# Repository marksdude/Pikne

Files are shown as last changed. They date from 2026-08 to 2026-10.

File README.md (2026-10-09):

# Pikne
A modular and repairable power bank
  
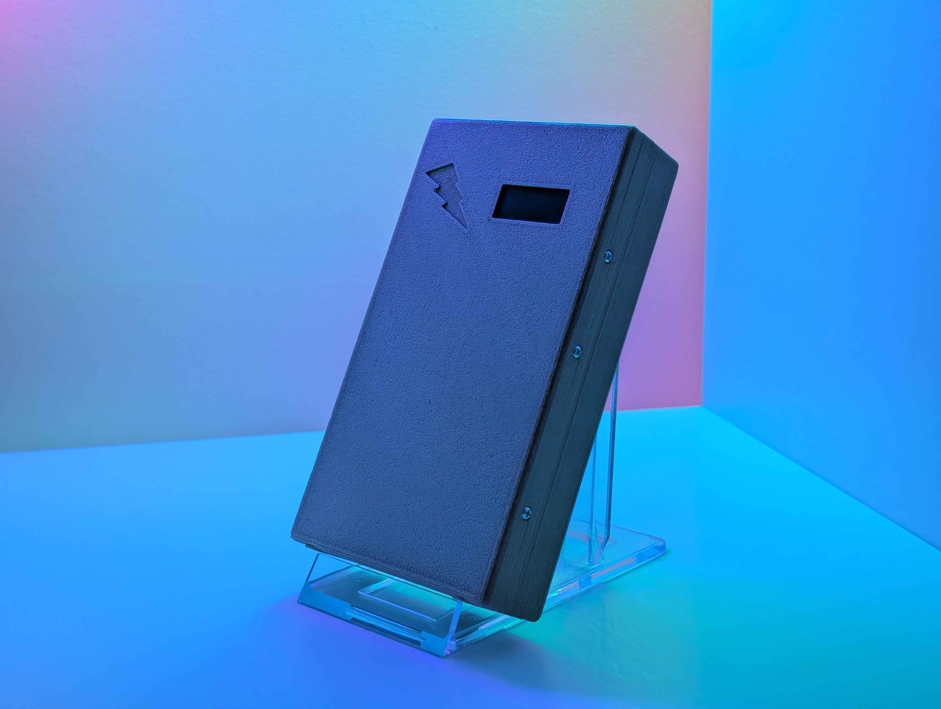
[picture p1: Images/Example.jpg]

Picture of rev 1.0 nonworking build
# Features:
- USB PD output up to 60W
- 0.91 inch OLED for status monitoring
- Attachable modules
- Repairable design
- 80WH capacity
- Based on the BQ25792 and TPS25751
- One USB-C output
# Modules:
- LED controller - Allows you to control LEDs with Home Assistant.  
  - Features:
    - Up to 2.5A output
    - 5V output
    - Home Assistant integration
    - Power monitoring on each output
    - 2 monochrome outputs, 1 RGB output and 1 addressable LED output 
      - **Note:** RGB and the monochrome outputs can't be used simultaneously.
    - ESP32-C3 based
- Flashlight
  - Features:
    - 6600lm max brightness
      - **Note:** The LEDs probably won't be able to run at max brightness for very long.
    - PWM dimmable
    - STM32L011F3 based
# Coming modules
- LiPo charger - Allows you to charge up to 4S LiPos from your power bank
# Why did I make this?
It all started because I was tired of changing the AA batteries in my mom's battery-powered lights. I wanted to make the process faster and less wasteful, so I thought it would be a good idea to design an easily removable, rechargeable battery pack for the lights and also integrate them with Home Assistant. The original idea was going to have 2 parts the battery pack and a controller board. They were supposed to be held together with magnets, connected with pogo pins and communicate over UART. Then I thought, why not turn the battery pack into a power bank so it could be used for things other than the lights? That's what I did. The idea of making the battery pack easily removable led me to make the power bank modular. That's how Pikne was born.

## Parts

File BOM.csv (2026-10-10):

 | Qty Needed | Min Purchase Qty | Unit | Price (total) (USD) | Price (total) (EUR) | Link | Notes
POWER BANK
Main PCB | 1 | 5 | pcs | 7,1 | 6,1 | https://jlcpcb.com/ | OSP Surface Finish, 4 layer, 60x30mm
Main PCB components | 1 | 1 | set | 39,81 | 34,49 |  | More info in the main PCB BOM, located in the main PCB folder
BMS PCB | 1 | 5 | pcs | 7,1 | 6,1 | https://jlcpcb.com/ | OSP Surface Finish, 4 layer, 50.85x18mm
BMS components | 1 | 1 | set | 18,01 | 15,52 |  | More info in the BMS BOM, located in the BMS folder
Battery | 4 | 1 | pcs | 16,01 | 13,8 | https://www.nkon.nl/en/samsung-inr21700-58e-5330mah-10-7a.html | 4 cells for 2S2P pack
isolation paper for the battery | 4 | 80 | pcs | 2,26 | 1,95 | https://www.nkon.nl/en/1x-20700-21700isolatiepapier-groen.html
Nickel strip for the battery | 0,4 | 1 | m | 3,77 | 3,25 | https://www.nkon.nl/en/1-meter-nikkel-batterijsoldeerstrip-10mm-0-10mm.html
Pogo connector PCB | 1 | 5 | pcs | 4,2 | 3,61 | https://jlcpcb.com/ | OSP Surface Finish, 2 layer, 39x10mm, black solder mask, 0.8mm thickness
Pogo connectors | 1 | 5 | pcs | 10,4 | 8,97 | https://www.amazon.de/-/en/Liseng-Magnetic-Connector-Position-Through/dp/B0B1771YT4 | Amazon seemed cheaper than Aliexpress, also used in the modules
ESD diode | 2 | 1 | pcs | 1,86 | 1,6 | https://www.mouser.ee/en/ProductDetail/Texas-Instruments/TPD2E2U06DCKRG4?qs=7%2F6SraaimPTS3zhvanrNFw%3D%3D | For the pogo connector, also used in the modules
JST connector | 2 | 1 | pcs | 1,1 | 0,95 | https://www.mouser.ee/en/ProductDetail/JST-Commercial/S3B-ZR-SM4A-TFLFSN?qs=QpmGXVUTftHs30qFaTPFrg%3D%3D | JST ZR S3B SM4A for the pogo connector, also used in the modules
Button PCB | 1 | 5 | pcs | 4,2 | 3,62 | https://jlcpcb.com/ | OSP Surface Finish, 2 layer, 29.9x8mm, black solder mask, 0.8mm thickness
Button | 1 | 1 | pcs | 1,13 | 0,97 | https://www.mouser.ee/en/ProductDetail/Omron-Electronics/B3U-1000P?qs=AO7BQMcsEu4ip80xyf2FwA%3D%3D
JST connector | 1 | 1 | pcs | 0,53 | 0,46 | https://www.mouser.ee/en/ProductDetail/JST-Commercial/S2B-ZR-SM4A-TFLFSN?qs=QpmGXVUTftFg0hrqdkvc8w%3D%3D | JST ZR S2B SM4A for the button
NTC | 4 | 1 | pcs | 2,69 | 2,33 | https://www.mouser.ee/en/ProductDetail/Semitec/103AT-2?qs=wgO0AD0o1vvcDzsKguD%252Bew%3D%3D | For sensing battery temperature
 |  |  | Total | 120,17 | 103,72
LED CONTROLLER MODULE
PCB | 1 | 5 | pcs | 4,1 | 3,53 | https://jlcpcb.com/ | OSP Surface Finish, 2 layer, 75x18.35mm, black solder mask, 0.8mm thickness
Components | 1 | 1 | set | 21,75 | 18,75 |  | More info in the LED controller BOM, located in /Modules/LED controller/PCB/LED controller
Pogo connector PCB | 1 | 5 | pcs | 4,2 | 3,61 | https://jlcpcb.com/ | OSP Surface Finish, 2 layer, 37.5x10mm, black solder mask, 0.8mm thickness
 |  |  | Total | 30,05 | 25,89
ALL TOGETHER
Power bank |  |  |  | 120,17 | 103,72
LED controller module |  |  |  | 30,05 | 25,89
 |  |  | Total | 150,22 | 129,61

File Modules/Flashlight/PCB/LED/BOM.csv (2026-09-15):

Id | Designator | Footprint | Quantity | Designation | Price (total) (EUR) | Link | Part number
1 | D1, D2, D3, D4, D5, D6, D7, D8, D9, D10, D11, D12, D13, D14, D15, D16, D17, D18, D19, D20, D21, D22, D23, D24, D25, D26, D27, D29, D30, D31 | Q9LR37 | 30 | LED | 23,22 | https://www.mouser.ee/en/ProductDetail/ams-OSRAM/GW-Q9LR37EMM2MF531?qs=dhCoiiGcT1LN8Ex%252B%252BcgNRA%3D%3D | GW Q9LR37EMM2MF531
2 | TH1 | R_0402_1005Metric | 1 | Thermistor_NTC | 0,09 | https://www.mouser.ee/en/ProductDetail/Murata-Electronics/NCU15XH103J6SRC | NCU15XH103J6SRC
 |  |  |  | Total (EUR) | 23,31
 |  |  |  | Total (USD) | 27,07

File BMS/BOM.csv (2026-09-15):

Id | Designator | Footprint | Quantity | Designation | Price (total) (euro) | Link
1 | C1, C3, C5 | C_0402_1005Metric | 3 | 0.1uf | 0,15 | https://www.mouser.ee/en/ProductDetail/Murata-Electronics/GRM155R62A104ME14D?qs=IPQhFcwEUOgMaa1bf1Gh1w%3D%3D
2 | C2, C4, C6, C7 | C_0402_1005Metric | 4 | 1uf | 0,27 | https://www.mouser.ee/en/ProductDetail/TAIYO-YUDEN/MCASE105SB5105KFNA01
3 | C8 | C_0402_1005Metric | 1 | 1nf | 0,09 | https://www.mouser.ee/en/ProductDetail/Murata-Electronics/GRM155R61A102KA01D
4 | D2 | D_SOD-323_HandSoldering | 1 | BAT54HT1G | 0,16 | https://www.mouser.ee/en/ProductDetail/onsemi/BAT54HT1G?qs=vLkC5FC1VN%252BK3ZQA%252ByHPIA%3D%3D
5 | IC1 | QFN40P400X400X80-33N-D | 1 | BQ41Z50RSNR | 4,88 | https://www.mouser.ee/en/ProductDetail/Texas-Instruments/BQ41Z50RSNR?qs=2FehpBK1j95h5MRSV2e3rA%3D%3D
6 | J2, J4 | JST_VH_S4P-VH_1x04_P3.96mm_Horizontal | 2 |  | 0,52 | https://www.mouser.ee/en/ProductDetail/JST-Commercial/S4P-VHLFSN?qs=QpmGXVUTftGoUBD%252BPjD3%2FQ%3D%3D
7 | J3 | JST_ZH_B3B-ZR_1x03_P1.50mm_Vertical | 1 | out | 0,21 | https://www.mouser.ee/en/ProductDetail/JST-Commercial/B3B-ZR-3.4LFSN?qs=cdbOS8ANM9A4HB4OVixO0g%3D%3D
8
9 | J5 | JST_ZH_B6B-ZR_1x06_P1.50mm_Vertical | 1 | in | 0,28 | https://www.mouser.ee/en/ProductDetail/JST-Commercial/B6B-ZR-3.4LFSN?qs=QpmGXVUTftFTUFNLJp%252BAEQ%3D%3D
10 | Q1, Q2 | TDSON-8-1 | 2 | CSD18512Q5B | 4,12 | https://www.mouser.ee/en/ProductDetail/Texas-Instruments/CSD18512Q5B?qs=34RfhUjJmKeWWuFTpy7f3A%3D%3D
11 | R1, R13 | R_0603_1608Metric | 2 | 10k | 0,09 | https://www.mouser.ee/en/ProductDetail/YAGEO/RT0603FRE1310KL?qs=sGAEpiMZZMtlubZbdhIBIE441mth93wmotyGspRJebc%3D
12 | R2, R3, R4, R10, R11 | R_0402_1005Metric | 5 | 100 ohm | 0,08 | https://www.mouser.ee/en/ProductDetail/Bourns/CR0402-FX-1000GLF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
13 | R5 | R_Shunt_Vishay_WSK2512_6332Metric_T2.21mm | 1 | R_Shunt | 2,55 | https://www.mouser.ee/en/ProductDetail/Vishay-Dale/WSK25123L000FEA?qs=l%252BoLuM8chxoqEmTKH2yXCw%3D%3D
14 | R6 | R_0603_1608Metric | 1 | 100 ohm | 0,09 | https://www.mouser.ee/en/ProductDetail/Vishay/CRCW0603100RFKECC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
15 | R7, R12 | R_0402_1005Metric | 2 | 5.1k | 0,08 | https://www.mouser.ee/en/ProductDetail/YAGEO/RC0402FR-075K1L
16 | R8, R9 | R_0402_1005Metric | 2 | 10M | 0,08 | https://www.mouser.ee/en/ProductDetail/YAGEO/AC0402DR-0710ML?qs=w%2Fv1CP2dgqr%252BP88vX9ZHng%3D%3D
17 | SW1, SW2 | SW_SPST_B3U-1000P | 2 |  | 1,87 | https://www.mouser.ee/en/ProductDetail/Omron-Electronics/B3U-1000P?qs=AO7BQMcsEu4ip80xyf2FwA%3D%3D
 |  |  |  | Total (EUR) | 15,52
 |  |  |  | Total (USD) | 18,01

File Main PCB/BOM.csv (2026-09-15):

Id | Designator | Footprint | Quantity | Designation | Price (total) (EUR) | Link | Part number
1 | C1, C13, C14, C16, C21, C23, C25, C33, C41, C46, C48, C40 | C_0402_1005Metric | 12 | 0.1uf | 0,18 | https://www.mouser.ee/en/ProductDetail/Murata-Electronics/GRM155R62A104ME14D?qs=IPQhFcwEUOgMaa1bf1Gh1w%3D%3D | GRM155R62A104ME14D
2 | C2 | C_0402_1005Metric | 1 | 1nf | 0,1 | https://www.mouser.ee/en/ProductDetail/Walsin/0402B102M500CT?qs=ZrPdAQfJ6DMOvVoHhNQARQ%3D%3D | 0402B102M500CT
3 | C3, C4 | C_0402_1005Metric_Pad0.74x0.62mm_HandSolder | 2 | 330pf | 0,16 | https://www.mouser.ee/en/ProductDetail/Samsung-Electro-Mechanics/CL05C331JB5NNNC | CL05C331JB5NNNC
4 | C5, C8, C27, C43 | C_0402_1005Metric | 4 | 10nf | 0,14 | https://www.mouser.ee/en/ProductDetail/Murata-Electronics/GRT155R71E103KE01J | GRT155R71E103KE01J
5 | C6, C20 | C_0402_1005Metric | 2 | 4.7uf | 0,4 | https://www.mouser.ee/en/ProductDetail/KYOCERA-AVX/KGM05CR51C475MH?qs=Jm2GQyTW%2Fbi2to8BOB9y6A%3D%3D | KGM05CR51C475MH
6 | C9 | C_0402_1005Metric_Pad0.74x0.62mm_HandSolder | 1 | 2.2nf | 0,1 | https://www.mouser.ee/en/ProductDetail/Murata-Electronics/GRM155R71H222KA01D?qs=sT7emLDNC7VMoN5Pn9EW7g%3D%3D | GRM155R71H222KA01D
7 | C10, C35 | C_0603_1608Metric_Pad1.08x0.95mm_HandSolder | 2 | 10uf | 0,21 | https://www.mouser.ee/en/ProductDetail/Murata-Electronics/GRM188R61A106ME69D | GRM188R61A106ME69D
8 | C11, C12, C42 | C_0805_2012Metric | 3 | 10uf | 1,21 | https://www.mouser.ee/en/ProductDetail/TDK/C2012X5R1V106K085AC?qs=6JAMGB%252BEdky%252BlYMcTLhFyA%3D%3D | C2012X5R1V106K085AC
9 | C15, C17, C18, C19, C22, C24, C26, C29, C30, C37, C36 | C_0603_1608Metric | 11 | 10uf | 0,97 | https://www.mouser.ee/en/ProductDetail/KYOCERA-AVX/0603YD106KAT2A | 0603YD106KAT2A
10 | C31, C32 | C_0402_1005Metric_Pad0.74x0.62mm_HandSolder | 2 | 0.047uf | 0,14 | https://www.mouser.ee/en/ProductDetail/Murata-Electronics/GRM155R71H473ME14J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 | GRM155R71H473ME14J
11
12 | C38, C39 | C_0805_2012Metric | 2 | 22uf | 1,1 | https://www.mouser.ee/en/ProductDetail/TAIYO-YUDEN/MSAST21GBB5226MTNC12?qs=tlsG%2FOw5FFifOAmFpx5Mxw%3D%3D | MSAST21GBB5226MTNC12
13 | C40
14 | C44 | C_0402_1005Metric | 1 | 1100pf | 0,13 | https://www.mouser.ee/en/ProductDetail/KEMET/C0402C112J4HACAUTO?qs=j%252B1pi9TdxUbzRsbRCfs5CQ%3D%3D | C0402C112J4HACAUTO
15 | C45 | C_0603_1608Metric | 1 | 4.7uf | 0,27 | https://www.mouser.ee/en/ProductDetail/Murata-Electronics/GRM188R6YA475ME15D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 | GRM188R6YA475ME15D
16 | C47 | C_0402_1005Metric_Pad0.74x0.62mm_HandSolder | 1 | 22pf | 0,11 | https://www.mouser.ee/en/ProductDetail/Walsin/0402N220K500CT | 0402N220K500CT
17 | C49 | CP_Radial_D5.0mm_P2.50mm | 1 | 100uf
18 | C50, C51 | C_1210_3225Metric_Pad1.33x2.70mm_HandSolder | 2 | 47uf | 1,15 | https://www.mouser.ee/en/ProductDetail/Samsung-Electro-Mechanics/CL32A476MOJNNNE | CL32A476MOJNNNE
19 | D1 | D_SOD-323_HandSoldering | 1 |  | 0,23 | https://www.mouser.ee/en/ProductDetail/Taiwan-Semiconductor/BAT42WSH-RRG?qs=jcD%2FCkGBYeNbLXauDmsPEg%3D%3D | BAT42WSH RRG
20 | D2 | D_SMC | 1 |  | 0,95 | https://www.mouser.ee/en/ProductDetail/Comchip-Technology/CDBC540-G?qs=tw%252BuQ%2FB6PO2ExpPYY64Vzw%3D%3D | CDBC540-G
21 | D3 | LED_0603_1608Metric | 1 | LED blue | 0,15 | https://www.mouser.ee/en/ProductDetail/Wurth-Elektronik/150060BS75000 | 150060BS75000
22 | J1 | USB_C_Receptacle_GCT_USB4125-xx-x-0190_6P_TopMnt_Horizontal | 1 | USB_C_Receptacle_PowerOnly_6P | 0,53 | https://www.mouser.ee/ProductDetail/GCT/USB4125-GF-A?qs=KUoIvG%2F9IlaIQ4zBJ6gLeA%3D%3D | USB4125-GF-A
23 | J2 | JST_VH_S4P-VH_1x04_P3.96mm_Horizontal | 1 | JST VH S4P | 0,26 | https://www.mouser.ee/en/ProductDetail/JST-Commercial/S4P-VHLFSN?qs=QpmGXVUTftGoUBD%252BPjD3%2FQ%3D%3D | S4P-VH(LF)(SN)
24 | J3, J4 | JST_ZH_B3B-ZR_1x03_P1.50mm_Vertical | 2 | JST ZH B3B | 0,41 | https://www.mouser.ee/en/ProductDetail/JST-Commercial/B3B-ZR-3.4LFSN?qs=cdbOS8ANM9A4HB4OVixO0g%3D%3D | B3B-ZR-3.4(LF)(SN)
25
26 | J6 | JST_ZH_B6B-ZR_1x06_P1.50mm_Vertical | 1 | JST ZH B6B | 0,28 | https://www.mouser.ee/en/ProductDetail/JST-Commercial/B6B-ZR-3.4LFSN?qs=QpmGXVUTftFTUFNLJp%252BAEQ%3D%3D | B6B-ZR-3.4(LF)(SN)
27 | L1 | L_Bourns_SRP1038C_10.0x10.0mm | 1 | 4.7uh | 0,74 | https://www.mouser.ee/en/ProductDetail/Bourns/SRP1038CC-4R7M?qs=1Kr7Jg1SGW%252BCPc6wLQ2Y6w%3D%3D | SRP1038CC-4R7M
28 | L3 | 7443845030010 | 1 | 1uH | 1,89 | https://www.mouser.ee/en/ProductDetail/Wurth-Elektronik/7443845030010?qs=a2MtRaTmNOQ4VejTFaA8vA%3D%3D | 7443845030010
29 | R1, R2, R26 | R_0603_1608Metric | 3 | 4.7k | 0,09 | https://www.mouser.ee/en/ProductDetail/YAGEO/AC0603JR-074K7L?qs=sGAEpiMZZMtlubZbdhIBIG07xJe44c5AqFOkmoxORGA%3D | AC0603JR-074K7L
30 | R3, R18, R4, R8, R9, R32 | R_0603_1608Metric | 6 | 10k | 0,09 | https://www.mouser.ee/en/ProductDetail/YAGEO/RT0603FRE1310KL?qs=sGAEpiMZZMtlubZbdhIBIE441mth93wmotyGspRJebc%3D | RT0603FRE1310KL
31
32 | R5, R6, R10, R11, R23 | R_0402_1005Metric | 5 | 10k | 0,08 | https://www.mouser.ee/en/ProductDetail/YAGEO/RC0402FR-0710KL?qs=sGAEpiMZZMtlubZbdhIBIPp9I5DmXL4oTFYHT01xAts%3D | RC0402FR-0710KL
33 | R7 | R_0402_1005Metric | 1 | 470k | 0,09 | https://www.mouser.ee/en/ProductDetail/YAGEO/RC0402FR-7D470KL | RC0402FR-7D470KL
34 | R12 | R_0402_1005Metric | 1 | 6.04k | 0,09 | https://www.mouser.ee/en/ProductDetail/YAGEO/RT0402FRE076K04L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 | RT0402FRE076K04L
35 | R13 | R_0603_1608Metric | 1 | 100k | 0,09 | https://www.mouser.ee/en/ProductDetail/YAGEO/RC0603FR-10100KL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 | RC0603FR-10100KL
36 | R14 | R_0603_1608Metric | 1 | 137k | 0,09 | https://www.mouser.ee/en/ProductDetail/YAGEO/AC0603FR-07137KL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 | AC0603FR-07137KL
37 | R15 | R_0402_1005Metric | 1 | 100 Ohm | 0,08 | https://www.mouser.ee/en/ProductDetail/YAGEO/AC0402FR-13100RL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 | AC0402FR-13100RL
38 | R16 | R_0603_1608Metric_Pad0.98x0.95mm_HandSolder | 1 | 5.23k | 0,09 | https://www.mouser.ee/en/ProductDetail/YAGEO/AC0603FR-075K23L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 | AC0603FR-075K23L
39 | R17 | R_0603_1608Metric_Pad0.98x0.95mm_HandSolder | 1 | 30.1k | 0,1 | https://www.mouser.ee/en/ProductDetail/Walsin/WR06X3012FTL?qs=sGAEpiMZZMtlubZbdhIBIFle1v8UTW4VXb4iJMPTIG0%3D | WR06X3012FTL
40 | R19, R20 | R_0402_1005Metric | 2 | 4.7k | 0,07 | https://www.mouser.ee/en/ProductDetail/YAGEO/RC0402JR-104K7L?qs=sGAEpiMZZMtlubZbdhIBIEgN9MQql2m6grJRvPfEuxM%3D | RC0402JR-104K7L
41 | R21 | R_0603_1608Metric | 1 | 10.2k | 0,09 | https://www.mouser.ee/en/ProductDetail/YAGEO/RT0603FRE0710K2L | RT0603FRE0710K2L
42 | R22 | R_0402_1005Metric | 1 | 27k | 0,09 | https://www.mouser.ee/en/ProductDetail/Walsin/WR04X2702FTL?qs=sGAEpiMZZMtlubZbdhIBIFle1v8UTW4V1ilyZzq3qow%3D | WR04X2702FTL
43
44 | R24 | R_0603_1608Metric | 1 | 47 Ohm | 0,09 | https://www.mouser.ee/en/ProductDetail/YAGEO/RT0603FRE0747RL | RT0603FRE0747RL
45 | R25 | R_0402_1005Metric | 1 | 1k | 0,09 | https://www.mouser.ee/en/ProductDetail/YAGEO/RC0402FR-101KL | RC0402FR-101KL
46
47 | R27 | R_0603_1608Metric_Pad0.98x0.95mm_HandSolder | 1 | 665k | 0,09 | https://www.mouser.ee/en/ProductDetail/SEI-Stackpole/RMCF0603FT665K | RMCF0603FT665K
48 | R28 | R_0603_1608Metric_Pad0.98x0.95mm_HandSolder | 1 | 130k | 0,09 | https://www.mouser.ee/en/ProductDetail/SEI-Stackpole/RMCF0603FT130K | RMCF0603FT130K
49 | R29 | R_0402_1005Metric_Pad0.72x0.64mm_HandSolder | 1 | 37.4k | 0,08 | https://www.mouser.ee/en/ProductDetail/YAGEO/RC0402FR-0737K4L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 | RC0402FR-0737K4L
50 | R30 | R_0603_1608Metric | 1 | 51.1 | 0,07 | https://www.mouser.ee/en/ProductDetail/SEI-Stackpole/RMCF0603FT51R1 | RMCF0603FT51R1
51 | R31 | R_0603_1608Metric | 1 | 1.96k | 0,09 | https://www.mouser.ee/en/ProductDetail/SEI-Stackpole/RMCF0603FT1K96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 | RMCF0603FT1K96
52 | R33 | R_0603_1608Metric | 1 | 10 Ohm | 0,08 | https://www.mouser.ee/en/ProductDetail/Walsin/WR06X100-JTL | WR06X100 JTL
53 | SW1, SW2 | SW_SPST_B3U-1000P | 2 | SW_Push | 1,87 | https://www.mouser.ee/en/ProductDetail/Omron-Electronics/B3U-1000P?qs=AO7BQMcsEu4ip80xyf2FwA%3D%3D | B3U-1000P
54 | TH1 | ntc | 1 | NTC 10K | 0,58 | https://www.mouser.ee/en/ProductDetail/Semitec/103AT-2?qs=wgO0AD0o1vvcDzsKguD%252Bew%3D%3D | 103AT-2
55 | TP1 | TestPoint_Pad_D1.0mm | 1
56 | TP2 | TestPoint_Pad_D1.0mm | 1
57 | TP3 | TestPoint_Pad_D1.0mm | 1
58 | TP4 | TestPoint_Pad_D1.0mm | 1
59 | TP5 | TestPoint_Pad_D1.0mm | 1
60 | U1 | QFN40P400X400X100-29N | 1 | BQ25792RQMR | 6,33 | https://www.mouser.ee/en/ProductDetail/Texas-Instruments/BQ25792RQMR?qs=81r%252BiQLm7BSrfMJlEm4Auw%3D%3D | BQ25792RQMR
61 | U2 | TQFP-32_7x7mm_P0.8mm | 1 | ATmega328P-A | 2,29 | https://www.mouser.ee/en/ProductDetail/Microchip-Technology/ATMEGA328P-AU?qs=K8BHR703ZXiCmmgp6%2FGNmQ%3D%3D | ATMEGA328P-AU
62 | U3 | SSD1306-0.91-OLED-4pin-128x32 | 1 | OLED 0.91 inch | 2,64 | https://www.aliexpress.com/item/1005008640108394.html
63 | U4 | WQFN38_REF_TEX | 1 | TPS25751DREFR | 2,57 | https://www.mouser.ee/en/ProductDetail/Texas-Instruments/TPS25751DREFR?qs=2wMNvWM5ZX4m402FYdvDNA%3D%3D | TPS25751DREFR
64 | U5 | WSON-6-1EP_2x2mm_P0.65mm_EP1x1.6mm | 1 | TVS2200DRV | 0,93 | https://www.mouser.ee/en/ProductDetail/Texas-Instruments/TVS2200DRVR?qs=W0yvOO0ixfHPbvei2cYdIw%3D%3D | TVS2200DRVR
65 | U6 | CONV_TPS54531DDAR | 1 | TPS54531DDAR | 1,95 | https://www.mouser.ee/en/ProductDetail/Texas-Instruments/TPS54531DDAR?qs=jA5Ki6243onykODzUePbag%3D%3D | TPS54531DDAR
66 | U7 | SOT-23-5 | 1 | TLV75533PDBV | 0,38 | https://www.mouser.ee/en/ProductDetail/Texas-Instruments/TLV75533PDBVR?qs=55YtniHzbhAKEwqeO2xJXQ%3D%3D | TLV75533PDBVR
67 | U8 | SOIC-8_3.9x4.9mm_P1.27mm | 1 | CAT24C256 | 0,63 | https://www.mouser.ee/en/ProductDetail/onsemi/CAT24C256WI-GT3?qs=rZgeL6XvLwaEqwp5Dppodg%3D%3D | CAT24C256WI-GT3
68 | U9 | VQFN10_RPW_TEX | 1 | TPS259461ARPW | 1,27 | https://www.mouser.ee/en/ProductDetail/Texas-Instruments/TPS259461ARPWR?qs=Wj%2FVkw3K%252BMCqhfGg0sy75g%3D%3D | TPS259461ARPWR
 |  |  |  | Total (EUR) | 35,07
 |  |  |  | Total (USD) | 40,69

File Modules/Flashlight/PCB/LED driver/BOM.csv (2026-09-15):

Id | Designator | Footprint | Quantity | Designation | Price (total) (EUR) | Link | Part number | alternative
1 | C1, C2, C27, C29 | C_1206_3216Metric | 4 | 10uf | 1 | https://www.mouser.ee/en/ProductDetail/TAIYO-YUDEN/MSAST31LSB5106KTNA01 | MSAST31LSB5106KTNA01
2 | C3, C19, C21 | C_0402_1005Metric | 3 | 1uf | 0,26 | https://www.mouser.ee/en/ProductDetail/Murata-Electronics/GRM155R61E105MA12D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 | GRM155R61E105MA12D
3 | C4 | C_0402_1005Metric | 1 | 470pf | 0,09 | https://www.mouser.ee/en/ProductDetail/Murata-Electronics/GCM155L81H471KA37D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 | GCM155L81H471KA37D
4 | C5 | C_0603_1608Metric | 1 | 4.7uf | 0,27 | https://www.mouser.ee/en/ProductDetail/Murata-Electronics/GRM188R6YA475ME15D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 | GRM188R6YA475ME15D
5 | C7, C25, C26, C30, C31, C37, C39 | C_0402_1005Metric | 7 | 0.1uf | 0,15 | https://www.mouser.ee/en/ProductDetail/Murata-Electronics/GRM155R62A104ME14D?qs=IPQhFcwEUOgMaa1bf1Gh1w%3D%3D | GRM155R62A104ME14D
6 | C17, C18, C24 | C_0603_1608Metric | 3 | 1uf | 0,19 | https://www.mouser.ee/en/ProductDetail/Samsung-Electro-Mechanics/CL10A105KA8NNND | CL10A105KA8NNND
7 | C38 | C_0603_1608Metric | 1 | 10uf | 0,09 | https://www.mouser.ee/en/ProductDetail/Samsung-Electro-Mechanics/CL10A105KA8NFNC | CL10A105KA8NFNC
8 | C28 | C_0805_2012Metric | 1 | 22uf | 0,15 | https://www.mouser.ee/en/ProductDetail/Samsung-Electro-Mechanics/CL21A226MQQNNNE | CL21A226MQQNNNE
9 | C32 | R_0402_1005Metric | 1 | 47pf | 0,09 | https://www.mouser.ee/en/ProductDetail/Murata-Electronics/GRM1555C1H470GA01D?qs=ouTquLLW2S7FCfuGSDD7Ng%3D%3D | GRM1555C1H470GA01D
10 | D1 | D_SMF | 1 | 1.2A | 0,4 | https://www.mouser.ee/en/ProductDetail/Vishay-Semiconductors/V3FL45-M3-H?qs=F5EMLAvA7ID5sYCrcwf4gA%3D%3D | V3FL45-M3/H
11 | D2 | D_SOD-323_HandSoldering | 1 | D_Schottky | 0,13 | https://www.mouser.ee/en/ProductDetail/onsemi/NSR0530HT1G?qs=raqtESnDWsD7hIBo7i2utQ%3D%3D | NSR0530HT1G
12 | D3 | SOT-323_SC-70 | 1 | ESDA25W | 0,36 | https://www.mouser.ee/en/ProductDetail/STMicroelectronics/ESDA25W?qs=f9uBznyCLhbO4Du0O%2FZtlA%3D%3D | ESDA25W
13 | D7 | LED_0603_1608Metric | 1 | LED | 0,28 | https://www.mouser.ee/en/ProductDetail/ams-OSRAM/KT-EELP41.12-S2U1-25-2X4X-5-R18 | KT EELP41.12-S2U1-25-2X4X-5-R18
14 | IC1 | SOP50P490X109-11N | 1 | LM3409MY_NOPB | 2,41 | https://www.mouser.ee/en/ProductDetail/Texas-Instruments/LM3409HVMYX-NOPB?qs=X1J7HmVL2ZHar3cROCA%252Bkw%3D%3D | LM3409HVMYX/NOPB
15 | J1 | USB4180030120C | 1 | USB4180-03-0120-C | 0,87 | https://www.mouser.ee/en/ProductDetail/GCT/USB4180-03-0120-C?qs=63Lh8XYXgjuxdGoYXvLhgw%3D%3D | USB4180-03-0120-C
16 | J3 | JST_ZH_B2B-ZR_1x02_P1.50mm_Vertical | 1 | NTC | 0,1 | https://www.mouser.ee/en/ProductDetail/JST-Commercial/B2B-ZRLFSN?qs=cdbOS8ANM9A%2F6QD8A97gUQ%3D%3D | B2B-ZR(LF)(SN)
17 | J5 | JST_ZH_B3B-ZR_1x03_P1.50mm_Vertical | 1 | UART | 0,21 | https://www.mouser.ee/en/ProductDetail/JST-Commercial/B3B-ZR-3.4LFSN?qs=cdbOS8ANM9A4HB4OVixO0g%3D%3D | B3B-ZR-3.4(LF)(SN)
18 | J6 | JST_ZH_B4B-ZR_1x04_P1.50mm_Vertical | 1 | Conn_01x04_Socket | 0,21 | https://www.mouser.ee/en/ProductDetail/JST-Commercial/B4B-ZR-3.4LFSN?qs=QpmGXVUTftEBHBFjwFopgw%3D%3D | B4B-ZR-3.4(LF)(SN)
19 | J7 | JST_XH_S2B-XH-A-1_1x02_P2.50mm_Horizontal | 1 | LED | 0,13 | https://www.mouser.ee/en/ProductDetail/JST-Commercial/S2B-XH-A-1LFSN?qs=QpmGXVUTftHhNeC%252BPQWeTw%3D%3D | S2B-XH-A-1(LF)(SN)
20 | L1 | L_Bourns_SRP1038C_10.0x10.0mm | 1 | 15uh | 0,84 | https://www.mouser.ee/en/ProductDetail/Bourns/SRP1038CC-150M?qs=1Kr7Jg1SGW%2FlW87F2iE1KQ%3D%3D | SRP1038CC-150M | SRP1038C-150M
21 | L2 | INDC3225X120N | 1 | 3.3uh | 0,34 | https://www.mouser.ee/en/ProductDetail/Bourns/SRP3212A-3R3M?qs=t7xnP681wgXp9Q%252BFP%252BQamQ%3D%3D | SRP3212A-3R3M
22 | Q1 | SISA35DNT1GE3 | 1 | SISA35DN-T1-GE3 | 0,67 | https://www.mouser.ee/en/ProductDetail/Vishay-Semiconductors/SISA35DN-T1-GE3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 | SISA35DN-T1-GE3
23 | Q10 | DMP1022UFDEQ7 | 1 | DMP3014SFDE-13 | 0,43 | https://www.mouser.ee/en/ProductDetail/Diodes-Incorporated/DMP3014SFDE-13?qs=2wMNvWM5ZX46gImKHQz6CA%3D%3D | DMP3014SFDE-13
24 | R1, R3 | R_0603_1608Metric | 2 | 10k | 0,09 | https://www.mouser.ee/en/ProductDetail/YAGEO/RT0603FRE1310KL?qs=sGAEpiMZZMtlubZbdhIBIE441mth93wmotyGspRJebc%3D | RT0603FRE1310KL
25 | R2, R38 | R_0603_1608Metric | 2 | 100k | 0,12 | https://www.mouser.ee/en/ProductDetail/YAGEO/RC0603FR-10100KL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 | RC0603FR-10100KL
26 | R4 | R_1206_3216Metric | 1 | 20m | 0,32 | https://www.mouser.ee/en/ProductDetail/Eaton-Electronics/MFSA1206R0200FCM | MFSA1206R0200FCM
27 | R5 | R_0603_1608Metric | 1 | 24.9k | 0,09 | https://www.mouser.ee/en/ProductDetail/SEI-Stackpole/RNCP0603FTD24K9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 | RNCP0603FTD24K9
28 | R6 | R_0603_1608Metric | 1 | 71.5k | 0,09 | https://www.mouser.ee/en/ProductDetail/Vishay/CRCW060371K5FKEA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 | CRCW060371K5FKEA
29 | R7, R9, R46 | R_0402_1005Metric | 3 | 100k | 0,09 | https://www.mouser.ee/en/ProductDetail/YAGEO/RC0402FR-07100KL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 | RC0402FR-07100KL
30 | R12 | R_0402_1005Metric | 1 | 1k | 0,09 | https://www.mouser.ee/en/ProductDetail/YAGEO/RC0402FR-101KL | RC0402FR-101KL
31 | R34, R50 | R_0402_1005Metric | 2 | 10k | 0,09 | https://www.mouser.ee/en/ProductDetail/YAGEO/RC0402FR-0710KL?qs=sGAEpiMZZMtlubZbdhIBIPp9I5DmXL4oTFYHT01xAts%3D | RC0402FR-0710KL
32 | R36 | R_0603_1608Metric | 1 | 470 | 0,09 | https://www.mouser.ee/en/ProductDetail/YAGEO/RC0603JR-07470RL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 | RC0603JR-07470RL
33 | R37 | R_0603_1608Metric | 1 | 1k | 0,09 | https://www.mouser.ee/en/ProductDetail/YAGEO/AC0603JR-131KL?qs=sGAEpiMZZMtlubZbdhIBIDoqZivquSRlVdLNHisjMZI%3D | AC0603JR-131KL
34 | R39 | R_0603_1608Metric | 1 | 22k | 0,09 | https://www.mouser.ee/en/ProductDetail/Walsin/WR06X223-JTL?qs=sGAEpiMZZMtlubZbdhIBIO6gLQ25xNI8WeQs8Hcjjdk%3D | WR06X223 JTL
35 | R41 | R_0402_1005Metric | 1 | 100 | 0,08 | https://www.mouser.ee/en/ProductDetail/YAGEO/AC0402FR-13100RL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 | AC0402FR-13100RL
36 | R42, R43, R44 | R_0603_1608Metric | 3 | 4.7k | 0,09 | https://www.mouser.ee/en/ProductDetail/YAGEO/AC0603JR-074K7L?qs=sGAEpiMZZMtlubZbdhIBIG07xJe44c5AqFOkmoxORGA%3D | AC0603JR-074K7L
37 | R45 | R_0402_1005Metric | 1 | 30k | 0,08 | https://www.mouser.ee/en/ProductDetail/Walsin/WR04X3002FTL | WR04X3002FTL
38 | R47 | R_0402_1005Metric | 1 | 50k | 0,09 | https://www.mouser.ee/en/ProductDetail/SEI-Stackpole/RNCF0402DKE50K0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 | RNCF0402DKE50K0
39 | R48 | R_0402_1005Metric | 1 | 135k | 0,15 | https://www.mouser.ee/en/ProductDetail/KOA-Speer/RN73H1ETTP1353F50?qs=n6Vcve68kq9DIyM7rzw%252BmQ%3D%3D | RN73H1ETTP1353F50
40 | SW1 | SW_Tactile_SPST_Angled_PTS645Vx39-2LFS | 1 | SW_Push | 0,3 | https://www.mouser.ee/en/ProductDetail/CK/PTS645VM39-2-LFS?qs=rqnA19JZHeSF5YTCbPSwgQ%3D%3D | PTS645VM39-2 LFS
41 | SW3 | SW_SPST_B3U-1000P | 1 | SW_Push | 0,94 | https://www.mouser.ee/en/ProductDetail/Omron-Electronics/B3U-1000P?qs=AO7BQMcsEu4ip80xyf2FwA%3D%3D | B3U-1000P
42 | TP1, TP2, TP3 | TestPoint_Pad_D1.0mm | 3 | TestPoint
43 | U1 | WSON-6-1EP_2x2mm_P0.65mm_EP1x1.6mm | 1 | TVS2200DRV | 0,93 | https://www.mouser.ee/en/ProductDetail/Texas-Instruments/TVS2200DRVR?qs=W0yvOO0ixfHPbvei2cYdIw%3D%3D | TVS2200DRVR
44 | U2 | QFN-24-1EP_4x4mm_P0.5mm_EP2.7x2.7mm | 1 | STUSB4500QTR | 0,91 | https://www.mouser.ee/en/ProductDetail/STMicroelectronics/STUSB4500QTR?qs=wUXugUrL1qyQbYMSzG1ujg%3D%3D | STUSB4500QTR
45 | U4 | TSSOP-20_4.4x6.5mm_P0.65mm | 1 | STM32L011F3Px | 1,58 | https://www.mouser.ee/en/ProductDetail/STMicroelectronics/STM32L011F3P6?qs=dTJS0cRn7oiJu0hvW9t64A%3D%3D | STM32L011F3P6
46 | U5 | SOTFL50P160X60-6N | 1 | TPS562246DRLR | 0,27 | https://www.mouser.ee/en/ProductDetail/Texas-Instruments/TPS562246DRLR?qs=IKkN%2F947nfANzK3phF20gw%3D%3D | TPS562246DRLR
47 | R40 | R_0402_1005Metric | 1 | 160 | 0,07 | https://www.mouser.ee/en/ProductDetail/YAGEO/RC0402JR-07160RL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 | RC0402JR-07160RL
 |  |  |  | Total (EUR) | 16,41
 |  |  |  | Total (USD) | 19,04

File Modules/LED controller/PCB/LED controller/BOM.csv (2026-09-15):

Id | Designator | Footprint | Quantity | Designation | Price (total) (EUR) | Link | Part number
1 | C1 | C_0603_1608Metric_Pad1.08x0.95mm_HandSolder | 1 | 4.7uf | 0,12 | https://www.mouser.ee/en/ProductDetail/Samsung-Electro-Mechanics/CL10A475KO8NNNC | CL10A475KO8NNNC
2 | C2, C11 | C_0603_1608Metric_Pad1.08x0.95mm_HandSolder | 2 | 22uf | 0,28 | https://www.mouser.ee/en/ProductDetail/Murata-Electronics/GRM188R60J226MEA0J | GRM188R60J226MEA0J
3 | C3 | C_0402_1005Metric_Pad0.74x0.62mm_HandSolder | 1 | 120pf | 0,09 | https://www.mouser.ee/en/ProductDetail/Murata-Electronics/GCM1555C1H121JA16D?qs=bGEzvQhTDnZomY%2Fu2q7nlQ%3D%3D | GCM1555C1H121JA16D
4 | C4 | C_0603_1608Metric_Pad1.08x0.95mm_HandSolder | 1 | 1uf | 0,09 | https://www.mouser.ee/en/ProductDetail/Samsung-Electro-Mechanics/CL10B105KQ8NNNC | CL10B105KQ8NNNC
5 | C5, C6, C7, C9, C10, C12, C13, C14 | C_0402_1005Metric_Pad0.74x0.62mm_HandSolder | 8 | 100nF | 0,15 | https://www.mouser.ee/en/ProductDetail/Murata-Electronics/GRM155R62A104ME14D?qs=IPQhFcwEUOgMaa1bf1Gh1w%3D%3D | GRM155R62A104ME14D
6 | C8 | C_0201_0603Metric_Pad0.64x0.40mm_HandSolder | 1 | 100nF | 0,09 | https://www.mouser.ee/en/ProductDetail/Murata-Electronics/GRM033R61C104KE18J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 | GRM033R61C104KE18J
7
8 | J1, J2 | JST_XH_S2B-XH-A-1_1x02_P2.50mm_Horizontal | 2 | LED | 0,26 | https://www.mouser.ee/en/ProductDetail/JST-Commercial/S2B-XH-A-1LFSN?qs=QpmGXVUTftHhNeC%252BPQWeTw%3D%3D | S2B-XH-A-1(LF)(SN)
9 | J3 | SAMESKY_UP32-1-C-H-G-BMT-P24 | 1 | UP32-1-C-H-G-BMT-P24 | 0,78 | https://www.mouser.ee/en/ProductDetail/Same-Sky/UP32-1-C-H-G-BMT-P24?qs=6avfeC6zeS4Y2l8mJTj2vg%3D%3D | UP32-1-C-H-G-BMT-P24
10 | J4 | JST_XH_S4B-XH-A-1_1x04_P2.50mm_Horizontal | 1 | RGB 2A max | 0,6 | https://www.mouser.ee/ProductDetail/JST-Commercial/S4B-XH-SM4-TBLFSN?qs=QpmGXVUTftFIPbbIXV0K6A%3D%3D | S4B-XH-SM4-TB(LF)(SN)
11 | J5 | JST_XH_S3B-XH-A-1_1x03_P2.50mm_Horizontal | 1 | RGB 2A max | 0,13 | https://www.mouser.ee/ProductDetail/JST-Commercial/S3B-XH-A-1LFSN?qs=QpmGXVUTftECC8e9QmmPaQ%3D%3D | S3B-XH-A-1(LF)(SN)
12 | J7 | JST_ZH_B3B-ZR_1x03_P1.50mm_Vertical | 1 | UART | 0,21 | https://www.mouser.ee/en/ProductDetail/JST-Commercial/B3B-ZR-3.4LFSN?qs=cdbOS8ANM9A4HB4OVixO0g%3D%3D | B3B-ZR-3.4(LF)(SN)
13 | L1 | L_1008_2520Metric_Pad1.43x2.20mm_HandSolder | 1 | 1uH | 0,22 | https://www.mouser.ee/ProductDetail/TDK/VLS252012HBX-1R0M-1?qs=uwKJARvjadPdw62CoJFM3g%3D%3D | VLS252012HBX-1R0M-1
14 | Q1, Q2, Q3 | SOT-23 | 3 | AO3400A | 0,38 | https://www.lcsc.com/product-detail/C20917.html | AO3400A
15 | R1 | R_0402_1005Metric_Pad0.72x0.64mm_HandSolder | 1 | 300k | 0,08 | https://www.mouser.ee/en/ProductDetail/YAGEO/AC0402FR-07300KL | AC0402FR-07300KL
16 | R2, R6, R7, R8, R10, R11 | R_0603_1608Metric_Pad0.98x0.95mm_HandSolder | 6 | 10k | 0,09 | https://www.mouser.ee/en/ProductDetail/YAGEO/RT0603FRE1310KL?qs=sGAEpiMZZMtlubZbdhIBIE441mth93wmotyGspRJebc%3D | RT0603FRE1310KL
17 | R3 | R_0603_1608Metric_Pad0.98x0.95mm_HandSolder | 1 | 100k | 0,09 | https://www.mouser.ee/en/ProductDetail/YAGEO/RC0603FR-10100KL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 | RC0603FR-10100KL
18 | R4, R5 | R_0603_1608Metric_Pad0.98x0.95mm_HandSolder | 2 | 5.1k | 0,09 | https://www.mouser.ee/en/ProductDetail/YAGEO/AC0603JR-075K1L?qs=sGAEpiMZZMtlubZbdhIBIG07xJe44c5AgRFh18pAOzY%3D | AC0603JR-075K1L
19 | R9, R12 | R_0603_1608Metric_Pad0.98x0.95mm_HandSolder | 2 | 4.7k | 0,09 | https://www.mouser.ee/en/ProductDetail/YAGEO/AC0603JR-074K7L?qs=sGAEpiMZZMtlubZbdhIBIG07xJe44c5AqFOkmoxORGA%3D | AC0603JR-074K7L
20 | R13, R14, R17, R18, R20, R21, R23, R24 | R_0402_1005Metric_Pad0.72x0.64mm_HandSolder | 8 | 10 Ohm | 0,08 | https://www.mouser.ee/en/ProductDetail/Bourns/CR0402-FX-10R0GLF | CR0402-FX-10R0GLF
21 | R15, R16, R19, R22 | R_0805_2012Metric_Pad1.20x1.40mm_HandSolder | 4 | 20m | 1,17 | https://www.mouser.ee/en/ProductDetail/Eaton-Electronics/MFSA0805R0200FIM?qs=By6Nw2ByBD2sPx6iVfyOsA%3D%3D | MFSA0805R0200FIM
22 | R25 | R_0402_1005Metric_Pad0.72x0.64mm_HandSolder | 1 | 150k | 0,09 | https://www.mouser.ee/en/ProductDetail/YAGEO/RC0402FR-07150KP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 | RC0402FR-07150KP
23 | R26, R27 | R_0402_1005Metric_Pad0.72x0.64mm_HandSolder | 2 | 22 Ohm | 0,08 | https://www.mouser.ee/en/ProductDetail/Bourns/CR0402-FX-22R0GLF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 | CR0402-FX-22R0GLF
24 | SW1, SW2, SW3 | SW_SPST_B3U-1000P | 3 |  | 2,81 | https://www.mouser.ee/en/ProductDetail/Omron-Electronics/B3U-1000P?qs=AO7BQMcsEu4ip80xyf2FwA%3D%3D | B3U-1000P
25
26
27 | TP1 | TestPoint_Pad_D1.0mm | 1 | 3.3V
28 | TP2 | TestPoint_Pad_D1.0mm | 1 | 5V
29 | U1, U2, U3, U5 | SOT-23-8 | 4 | INA219AxDCN | 7,28 | https://www.mouser.ee/ProductDetail/Texas-Instruments/INA219AIDCNR?qs=NNt36bEIu0tiHc879dL2eg%3D%3D | INA219AIDCNR
30 | U4 | SOT-23-6 | 1 | TPS62A02APDDC | 0,21 | https://www.mouser.ee/ProductDetail/Texas-Instruments/TPS62A02APDDCR?qs=ZcfC38r4PotJY8Nb5BNo3Q%3D%3D | TPS62A02APDDCR
31 | U7 | ESP32-C3-WROOM-02U | 1 | ESP32-C3-WROOM-02 | 3,19 | https://www.mouser.ee/en/ProductDetail/Espressif-Systems/ESP32-C3-WROOM-02U-N4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 | ESP32-C3-WROOM-02U-N4
 |  |  |  | Total (EUR) | 18,75
 |  |  |  | Total (USD) | 21,75

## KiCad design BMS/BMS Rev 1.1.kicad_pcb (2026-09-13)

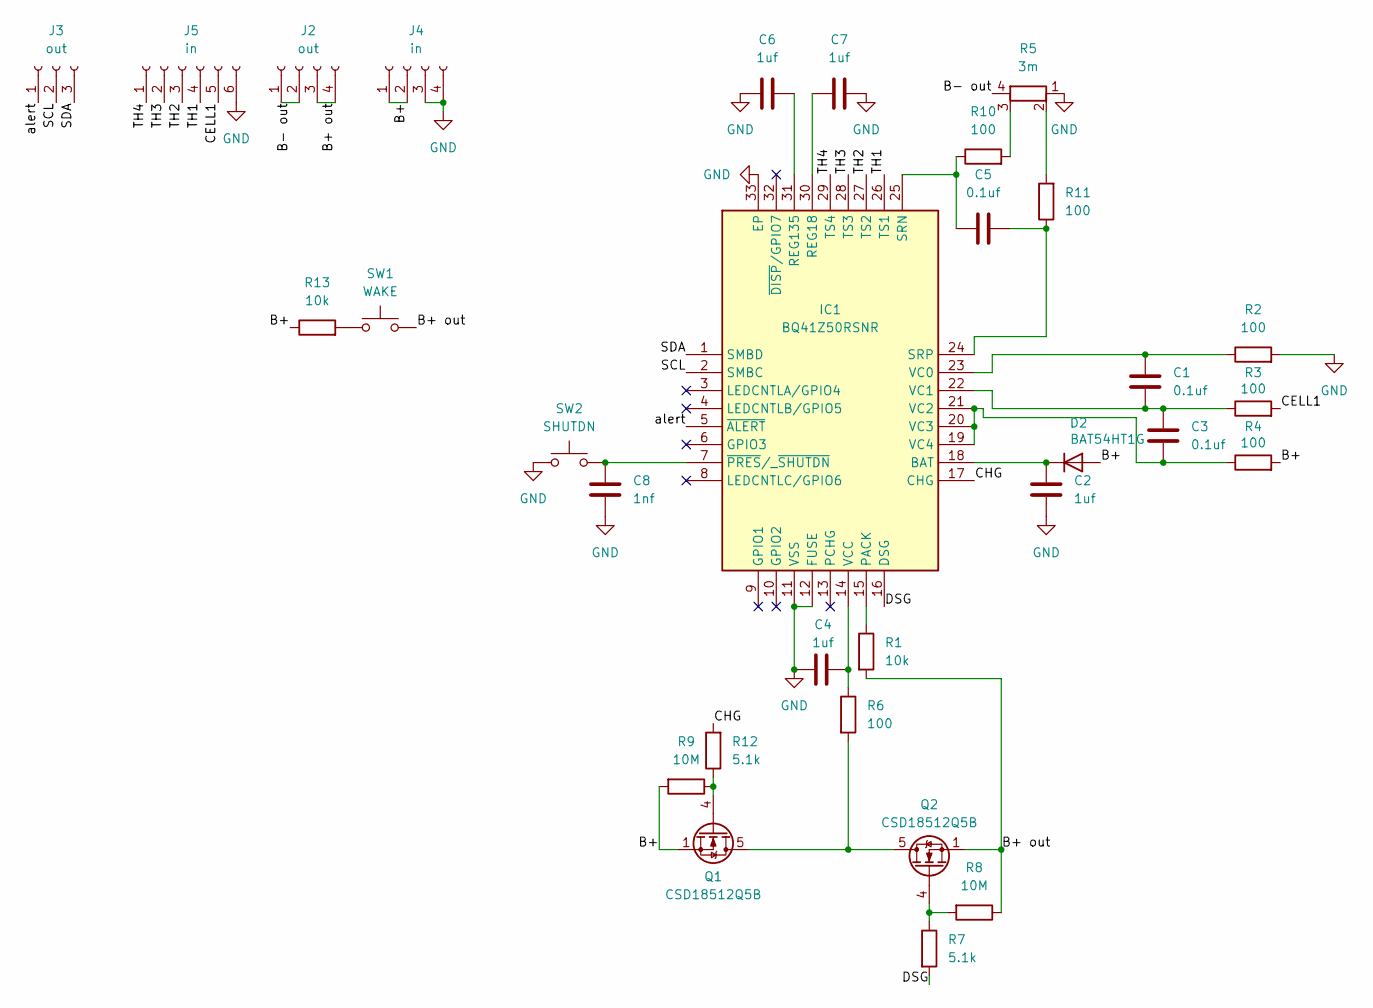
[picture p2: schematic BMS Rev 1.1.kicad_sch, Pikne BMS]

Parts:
C1, C3, C5: 0.1uf; C_0402_1005Metric
C2, C4, C6, C7: 1uf; C_0402_1005Metric
C8: 1nf; C_0402_1005Metric
D2: BAT54HT1G; D_SOD-323_HandSoldering
IC1: BQ41Z50RSNR; QFN40P400X400X80-33N-D; Manufacturer_Part_Number BQ41Z50RSNR
J2: out; JST_VH_S4P-VH_1x04_P3.96mm_Horizontal
J3: out; JST_ZH_B3B-ZR_1x03_P1.50mm_Vertical
J4: in; JST_VH_S4P-VH_1x04_P3.96mm_Horizontal
J5: in; JST_ZH_B6B-ZR_1x06_P1.50mm_Vertical
Q1, Q2: CSD18512Q5B; TDSON-8-1
R1, R13: 10k; R_0603_1608Metric
R2, R3, R4, R10, R11: 100; R_0402_1005Metric
R5: 3m; R_Shunt_Vishay_WSK2512_6332Metric_T2.21mm
R6: 100; R_0603_1608Metric
R7, R12: 5.1k; R_0402_1005Metric
R8, R9: 10M; R_0402_1005Metric
SW1: WAKE; SW_SPST_B3U-1000P
SW2: SHUTDN; SW_SPST_B3U-1000P

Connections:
/B+: D2.2 (A), J4.1, J4.2, Q1.1 (S), Q1.2 (S), Q1.3 (S), R4.2, R9.2, R13.1
/B+ out: J2.3, J2.4, Q2.1 (S), Q2.2 (S), Q2.3 (S), R1.2, R8.1, SW1.2
/B- out: J2.1, J2.2, R5.4
/CELL1: J5.5, R3.2
/CHG: IC1.17 (CHG), R12.2
/DSG: IC1.16 (DSG), R7.2
/SCL: IC1.2 (SMBC), J3.2
/SDA: IC1.1 (SMBD), J3.3
/TH1: IC1.26 (TS1), J5.4
/TH2: IC1.27 (TS2), J5.3
/TH3: IC1.28 (TS3), J5.2
/TH4: IC1.29 (TS4), J5.1
/alert: IC1.5 (~ALERT), J3.1
GND: C2.2, C4.1, C6.1, C7.2, C8.1, IC1.11 (VSS), IC1.12 (FUSE), IC1.33 (EP), J4.3, J4.4, J5.6, R2.2, R5.1, SW2.1
unnamed: C2.1, D2.1 (K), IC1.18 (BAT)
unnamed: IC1.15 (PACK), R1.1
unnamed: C7.1, IC1.30 (REG18)
unnamed: C6.2, IC1.31 (REG135)
unnamed: C5.1, IC1.25 (SRN), R10.1
unnamed: C5.2, IC1.24 (SRP), R11.1
unnamed: C1.1, IC1.23 (VC0), R2.1
unnamed: C1.2, C3.1, IC1.22 (VC1), R3.1
unnamed: C3.2, IC1.19 (VC4), IC1.20 (VC3), IC1.21 (VC2), R4.1
unnamed: C4.2, IC1.14 (VCC), R6.1
unnamed: C8.2, IC1.7 (~PRES/_~SHUTDN), SW2.2
unnamed: Q1.5 (D), Q2.5 (D), R6.2
unnamed: Q1.4 (G), R9.1, R12.1
unnamed: Q2.4 (G), R7.1, R8.2
unnamed: R5.3, R10.2
unnamed: R5.2, R11.2
unnamed: R13.2, SW1.1

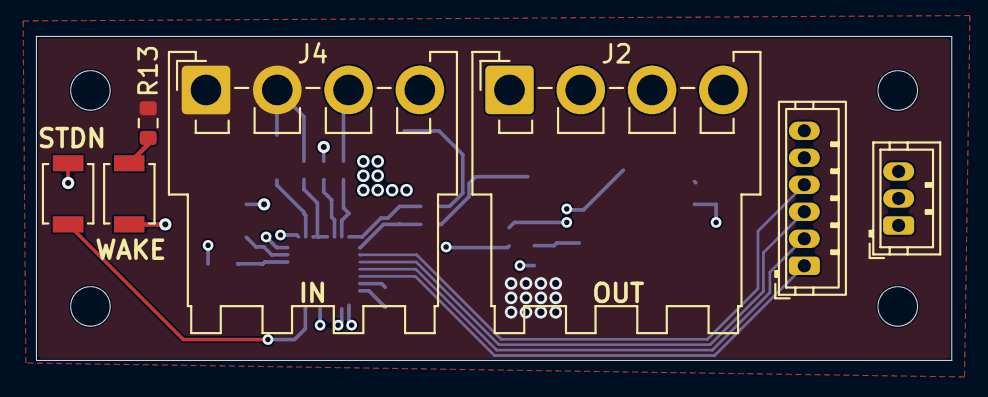
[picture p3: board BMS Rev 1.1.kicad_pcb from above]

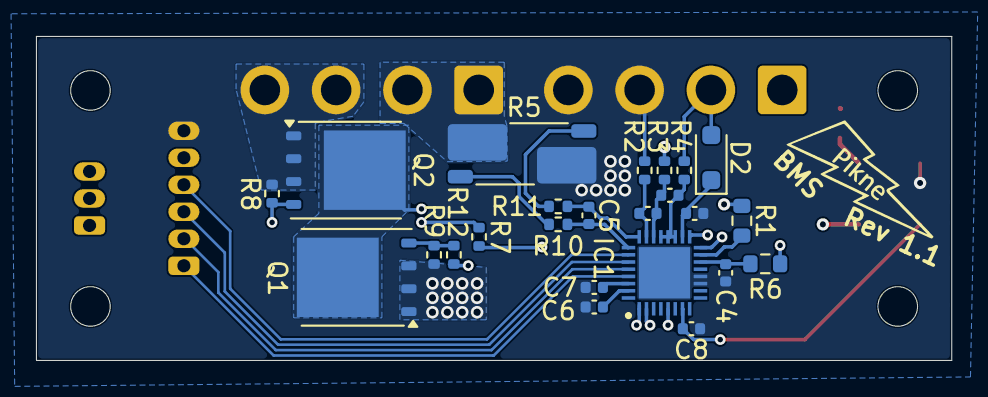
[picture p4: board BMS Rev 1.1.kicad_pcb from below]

Board: 4 copper layers, 50.9 x 18.0 mm, 31 parts (24 on the bottom side), 31 nets.

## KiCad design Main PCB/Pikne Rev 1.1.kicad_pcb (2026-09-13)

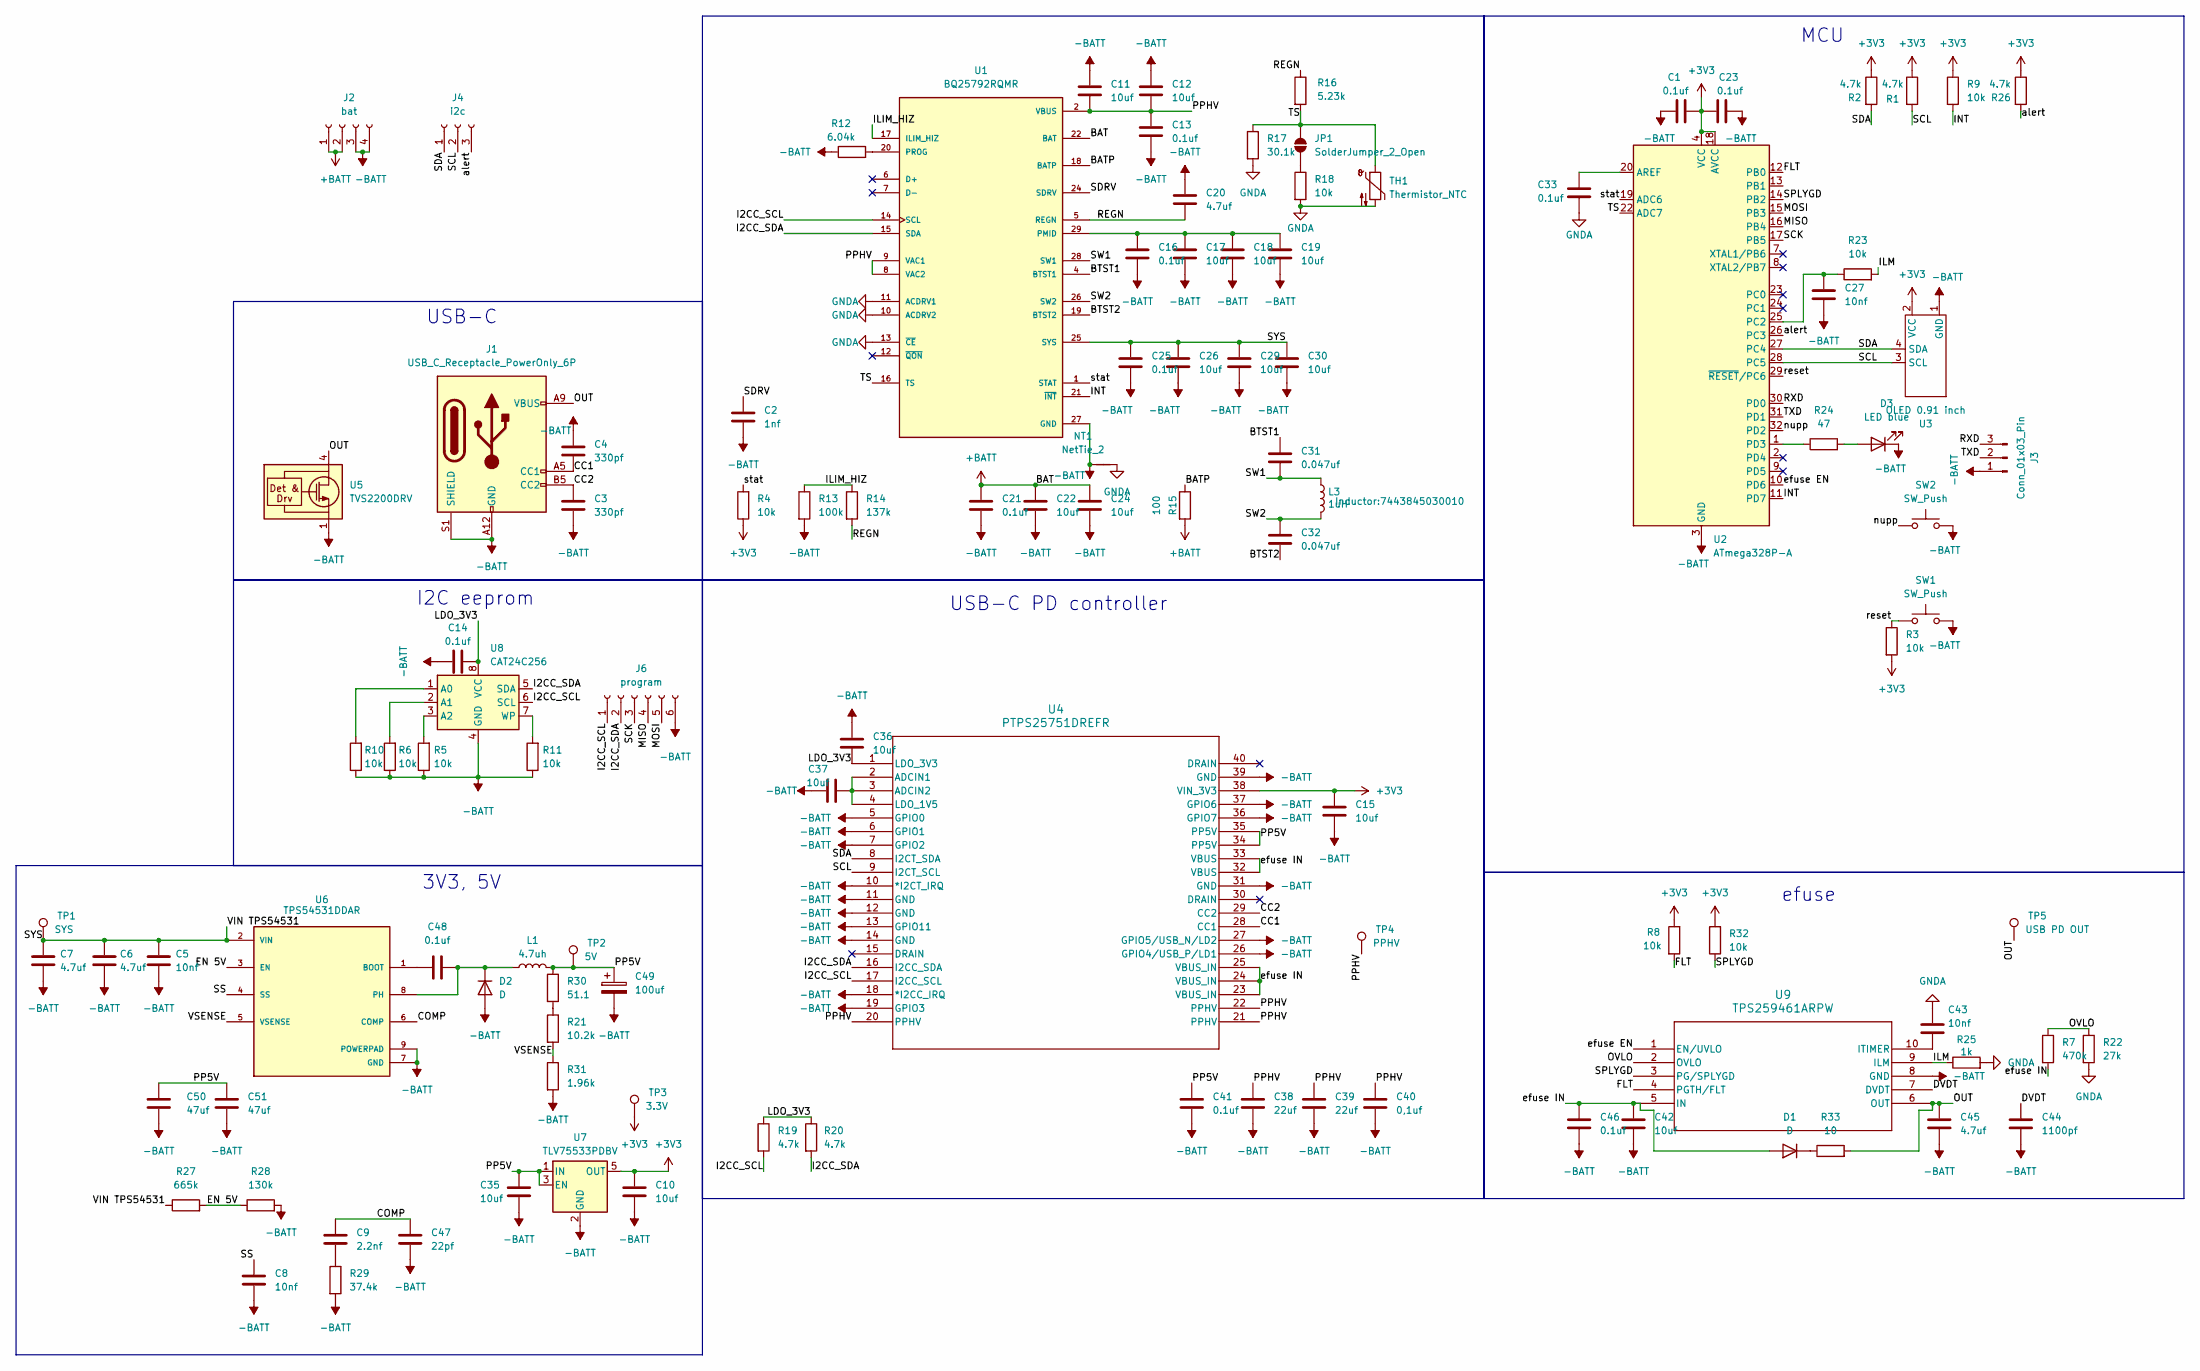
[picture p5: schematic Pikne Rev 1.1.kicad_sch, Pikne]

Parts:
C1, C13, C14, C16, C21, C23, C25, C33, C41, C46, C48: 0.1uf; C_0402_1005Metric
C2: 1nf; C_0402_1005Metric
C3, C4: 330pf; C_0402_1005Metric_Pad0.74x0.62mm_HandSolder
C5, C8, C27, C43: 10nf; C_0402_1005Metric
C6, C20: 4.7uf; C_0402_1005Metric
C7: 4.7uf; C_0402_1005Metric_Pad0.74x0.62mm_HandSolder
C9: 2.2nf; C_0402_1005Metric_Pad0.74x0.62mm_HandSolder
C10, C35: 10uf; C_0603_1608Metric_Pad1.08x0.95mm_HandSolder
C11, C12, C42: 10uf; C_0805_2012Metric
C15, C17, C18, C19, C22, C24, C26, C29, C30, C36, C37: 10uf; C_0603_1608Metric
C31, C32: 0.047uf; C_0402_1005Metric_Pad0.74x0.62mm_HandSolder
C38, C39: 22uf; C_0805_2012Metric
C40: 0,1uf; C_0402_1005Metric
C44: 1100pf; C_0402_1005Metric
C45: 4.7uf; C_0603_1608Metric
C47: 22pf; C_0402_1005Metric_Pad0.74x0.62mm_HandSolder
C49: 100uf; CP_Radial_D5.0mm_P2.50mm
C50, C51: 47uf; C_1210_3225Metric_Pad1.33x2.70mm_HandSolder
D1: D; D_SOD-323_HandSoldering
D2: D; D_SMC
D3: LED blue; LED_0603_1608Metric
J1: USB_C_Receptacle_PowerOnly_6P; USB_C_Receptacle_GCT_USB4125-xx-x-0190_6P_TopMnt_Horizontal
J2: bat; JST_VH_S4P-VH_1x04_P3.96mm_Horizontal
J3: Conn_01x03_Pin; JST_ZH_B3B-ZR_1x03_P1.50mm_Vertical
J4: i2c; JST_ZH_B3B-ZR_1x03_P1.50mm_Vertical
J6: program; JST_ZH_B6B-ZR_1x06_P1.50mm_Vertical
JP1: SolderJumper_2_Open; SolderJumper-2_P1.3mm_Open_Pad1.0x1.5mm
L1: 4.7uh; L_Bourns_SRP1038C_10.0x10.0mm
L3: 1uH; 7443845030010
NT1: NetTie_2; NetTie-2_THT_Pad0.3mm
R1, R2: 4.7k; R_0603_1608Metric_Pad0.98x0.95mm_HandSolder
R3, R18: 10k; R_0603_1608Metric_Pad0.98x0.95mm_HandSolder
R4, R8, R9, R32: 10k; R_0603_1608Metric
R5, R6, R10, R11: 10k; R_0402_1005Metric_Pad0.72x0.64mm_HandSolder
R7: 470k; R_0402_1005Metric
R12: 6.04k; R_0402_1005Metric
R13: 100k; R_0603_1608Metric
R14: 137k; R_0603_1608Metric
R15: 100; R_0402_1005Metric
R16: 5.23k; R_0603_1608Metric_Pad0.98x0.95mm_HandSolder
R17: 30.1k; R_0603_1608Metric_Pad0.98x0.95mm_HandSolder
R19, R20: 4.7k; R_0402_1005Metric
R21: 10.2k; R_0603_1608Metric
R22: 27k; R_0402_1005Metric
R23: 10k; R_0402_1005Metric
R24: 47; R_0603_1608Metric
R25: 1k; R_0402_1005Metric
R26: 4.7k; R_0603_1608Metric
R27: 665k; R_0603_1608Metric_Pad0.98x0.95mm_HandSolder
R28: 130k; R_0603_1608Metric_Pad0.98x0.95mm_HandSolder
R29: 37.4k; R_0402_1005Metric_Pad0.72x0.64mm_HandSolder
R30: 51.1; R_0603_1608Metric
R31: 1.96k; R_0603_1608Metric
R33: 10; R_0603_1608Metric
SW1, SW2: SW_Push; SW_SPST_B3U-1000P
TH1: Thermistor_NTC; ntc
TP1: SYS; TestPoint_Pad_D1.0mm
TP2: 5V; TestPoint_Pad_D1.0mm
TP3: 3.3V; TestPoint_Pad_D1.0mm
TP4: PPHV; TestPoint_Pad_D1.0mm
TP5: USB PD OUT; TestPoint_Pad_D1.0mm
U1: BQ25792RQMR; QFN40P400X400X100-29N; PARTREV 11/2019
U2: ATmega328P-A; TQFP-32_7x7mm_P0.8mm
U3: OLED 0.91 inch; SSD1306-0.91-OLED-4pin-128x32
U4: PTPS25751DREFR; WQFN38_REF_TEX
U5: TVS2200DRV; WSON-6-1EP_2x2mm_P0.65mm_EP1x1.6mm
U6: TPS54531DDAR; CONV_TPS54531DDAR; PARTREV A
U7: TLV75533PDBV; SOT-23-5
U8: CAT24C256; SOIC-8_3.9x4.9mm_P1.27mm
U9: TPS259461ARPW; VQFN10_RPW_TEX

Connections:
+3V3: C1.2, C10.1, C15.1, C23.1, R1.1, R2.1, R3.2, R4.1, R8.1, R9.1, R26.1, R32.2, TP3.1 (1_1), U2.4 (VCC), U2.6 (VCC), U2.18 (AVCC), U3.2 (VCC), U4.38 (VIN_3V3), U7.5 (OUT)
+BATT: C21.1, C22.1, C24.1, J2.1, J2.2, R15.2, U1.22 (BAT), U1.23 (BAT)
-BATT: C1.1, C2.1, C3.2, C4.1, C5.2, C6.2, C7.1, C8.2, C10.2, C11.1, C12.1, C13.1, C14.2, C15.2, C16.2, C17.2, C18.2, C19.2, C20.1, C21.2, C22.2, C23.2, C24.2, C25.2, C26.2, C27.2, C29.2, C30.2, C35.2, C36.2, C37.2, C38.2, C39.2, C40.2, C41.2, C42.2, C44.2, C45.2, C46.2, C47.2, C49.2, C50.2, C51.2, D2.2 (A), D3.1 (K), J1.A12 (GND), J1.B12 (GND), J1.S1 (SHIELD), J2.3, J2.4, J3.1, J6.6, NT1.1, R5.1, R6.1, R10.1, R11.1, R12.1, R13.2, R28.2, R29.2, R31.2, SW1.2, SW2.2, U1.27 (GND), U2.3 (GND), U2.5 (GND), U2.21 (GND), U3.1 (GND), U4.5 (GPIO0), U4.6 (GPIO1), U4.7 (GPIO2), U4.10 (*I2CT_IRQ), U4.11 (GND), U4.12 (GND), U4.13 (GPIO11), U4.14 (GND), U4.18 (*I2CC_IRQ), U4.19 (GPIO3), U4.26 (GPIO4/USB_P/LD1), U4.27 (GPIO5/USB_N/LD2), U4.31 (GND), U4.36 (GPIO7), U4.37 (GPIO6), U4.39 (GND), U5.1 (GND), U5.2 (GND), U5.3 (GND), U5.7 (GND), U6.7 (GND), U6.9 (POWERPAD), U6.10, U6.11, U6.12, U6.13, U6.14, U6.15, U7.2 (GND), U8.4 (GND), U9.8 (GND)
/BATP: R15.1, U1.18 (BATP)
/BTST1: C31.1, U1.4 (BTST1)
/BTST2: C32.2, U1.19 (BTST2)
/CC1: C4.2, J1.A5 (CC1), U4.28 (CC1)
/CC2: C3.1, J1.B5 (CC2), U4.29 (CC2)
/COMP: C9.1, C47.1, U6.6 (COMP)
/DVDT: C44.1, U9.7 (DVDT)
/EN 5V: R27.2, R28.1, U6.3 (EN)
/FLT: R8.2, U2.12 (PB0), U9.4 (PGTH/FLT)
/I2CC_SCL: J6.1, R19.2, U1.14 (SCL), U4.17 (I2CC_SCL), U8.6 (SCL)
/I2CC_SDA: J6.2, R20.2, U1.15 (SDA), U4.16 (I2CC_SDA), U8.5 (SDA)
/ILIM_HIZ: R13.1, R14.1, U1.17 (ILIM_HIZ)
/ILM: R23.2, R25.1, U9.9 (ILM)
/INT: R9.2, U1.21 (~INT), U2.11 (PD7)
/LDO_3V3: C14.1, C36.1, R19.1, R20.1, U4.1 (LDO_3V3), U8.8 (VCC)
/MISO: J6.4, U2.16 (PB4)
/MOSI: J6.5, U2.15 (PB3)
/OUT: C45.1, J1.A9 (VBUS), J1.B9 (VBUS), R33.2, TP5.1 (1_1), U5.4 (IN), U5.5 (IN), U5.6 (IN), U9.6 (OUT)
/OVLO: R7.1, R22.1, U9.2 (OVLO)
/PP5V: C35.1, C41.1, C49.1, C50.1, C51.1, L1.2, R30.1, TP2.1 (1_1), U4.34 (PP5V), U4.35 (PP5V), U7.1 (IN), U7.3 (EN)
/REGN: C20.2, R14.2, R16.1, U1.5 (REGN)
/RXD: J3.3, U2.30 (PD0)
/SCK: J6.3, U2.17 (PB5)
/SCL: J4.2, R1.2, U2.28 (PC5), U3.3 (SCL), U4.9 (I2CT_SCL)
/SDA: J4.1, R2.2, U2.27 (PC4), U3.4 (SDA), U4.8 (I2CT_SDA)
/SDRV: C2.2, U1.24 (SDRV)
/SPLYGD: R32.1, U2.14 (PB2), U9.3 (PG/SPLYGD)
/SS: C8.1, U6.4 (SS)
/SW1: C31.2, L3.1, U1.28 (SW1)
/SW2: C32.1, L3.2, U1.26 (SW2)
/SYS: C5.1, C6.1, C7.2, C25.1, C26.1, C29.1, C30.1, R27.1, TP1.1 (1_1), U1.25 (SYS), U6.2 (VIN)
/TS: JP1.1 (A), R16.2, R17.1, TH1.1, U1.16 (TS), U2.22 (ADC7)
/TXD: J3.2, U2.31 (PD1)
/VSENSE: R21.2, R31.1, U6.5 (VSENSE)
/alert: J4.3, R26.2, U2.26 (PC3)
/efuse EN: U2.10 (PD6), U9.1 (EN/UVLO)
/efuse IN: C42.1, C46.1, D1.2 (A), R7.2, U4.23 (VBUS_IN), U4.24 (VBUS_IN), U4.25 (VBUS_IN), U4.32 (VBUS), U4.33 (VBUS), U9.5 (IN)
/nupp: SW2.1, U2.32 (PD2)
/reset: R3.1, SW1.1, U2.29 (~RESET/PC6)
/stat: R4.2, U1.1 (STAT), U2.19 (ADC6)
GNDA: C33.2, C43.1, NT1.2, R17.2, R18.2, R22.2, R25.2, TH1.2, U1.10 (ACDRV2), U1.11 (ACDRV1), U1.13 (~CE)
unnamed: C9.2, R29.1
unnamed: D1.1 (K), R33.1
unnamed: C48.2, D2.1 (K), L1.1, U6.8 (PH)
unnamed: D3.2 (A), R24.2
unnamed: JP1.2 (B), R18.1
unnamed: R21.1, R30.2
unnamed: C16.1, C17.1, C18.1, C19.1, U1.29 (PMID)
unnamed: R12.2, U1.20 (PROG)
unnamed: C33.1, U2.20 (AREF)
unnamed: C27.1, R23.1, U2.25 (PC2)
unnamed: R24.1, U2.1 (PD3)
unnamed: C37.1, U4.2 (ADCIN1), U4.3 (ADCIN2), U4.4 (LDO_1V5)
unnamed: C48.1, U6.1 (BOOT)
unnamed: R10.2, U8.1 (A0)
unnamed: R6.2, U8.2 (A1)
unnamed: R5.2, U8.3 (A2)
unnamed: R11.2, U8.7 (WP)
unnamed: C43.2, U9.10 (ITIMER)
VBUS: C11.2, C12.2, C13.2, C38.1, C39.1, C40.1, TP4.1 (1_1), U1.2 (VBUS), U1.3 (VBUS), U1.8 (VAC2), U1.9 (VAC1), U4.20 (PPHV), U4.21 (PPHV), U4.22 (PPHV)

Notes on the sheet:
USB-C PD controller
MCU
3V3, 5V
I2C eeprom
efuse
USB-C

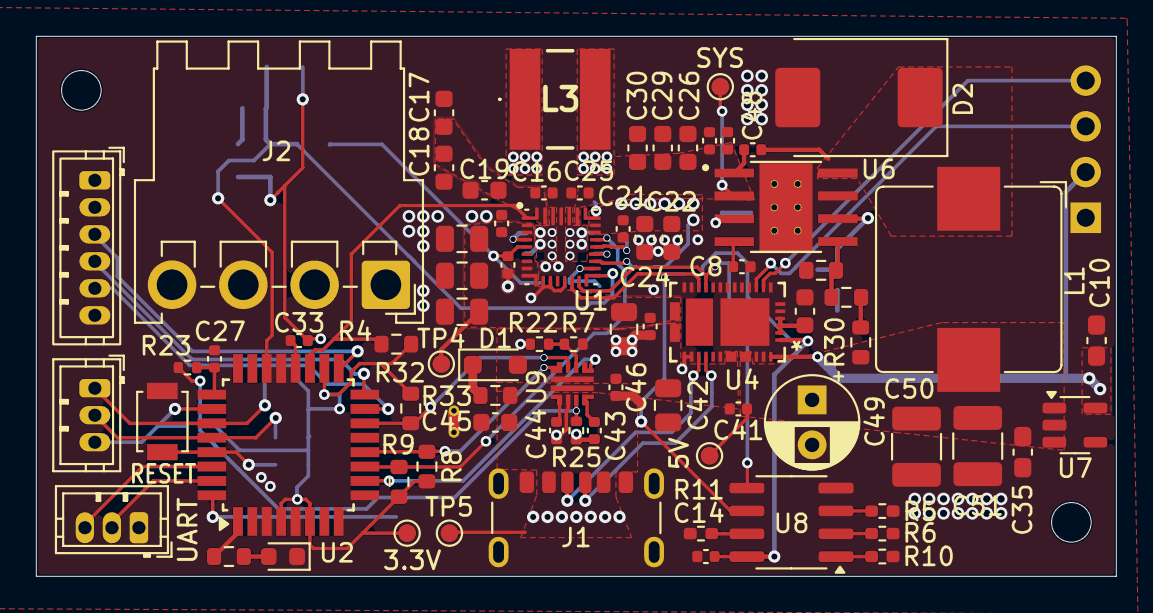
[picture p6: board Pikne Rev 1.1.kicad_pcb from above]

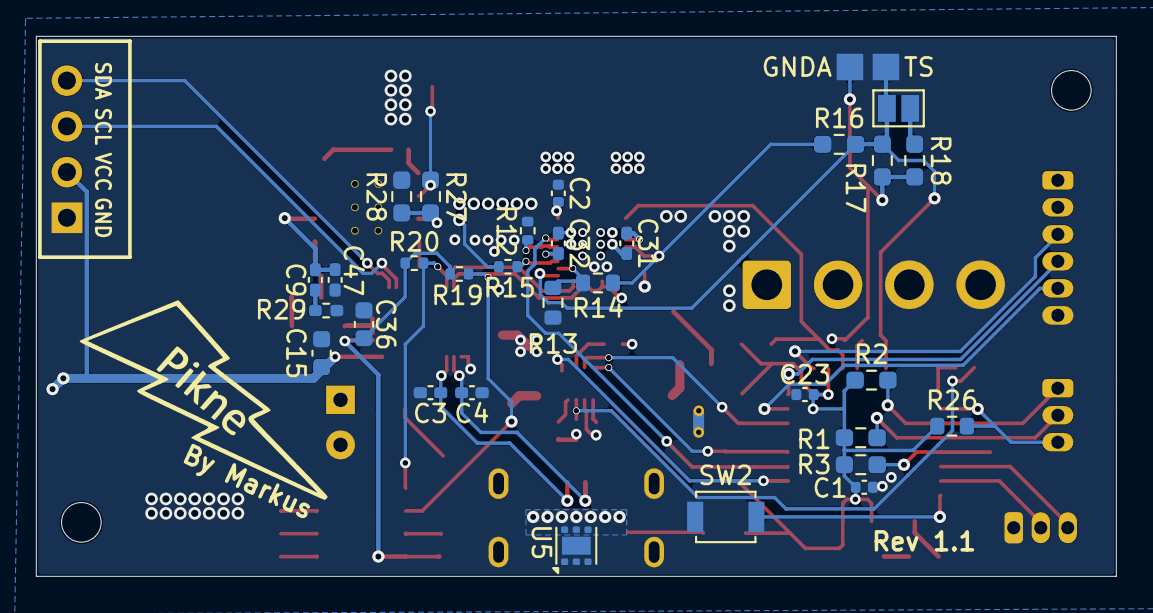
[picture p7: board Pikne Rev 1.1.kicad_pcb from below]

Board: 4 copper layers, 60.0 x 30.0 mm, 110 parts (32 on the bottom side), 63 nets.

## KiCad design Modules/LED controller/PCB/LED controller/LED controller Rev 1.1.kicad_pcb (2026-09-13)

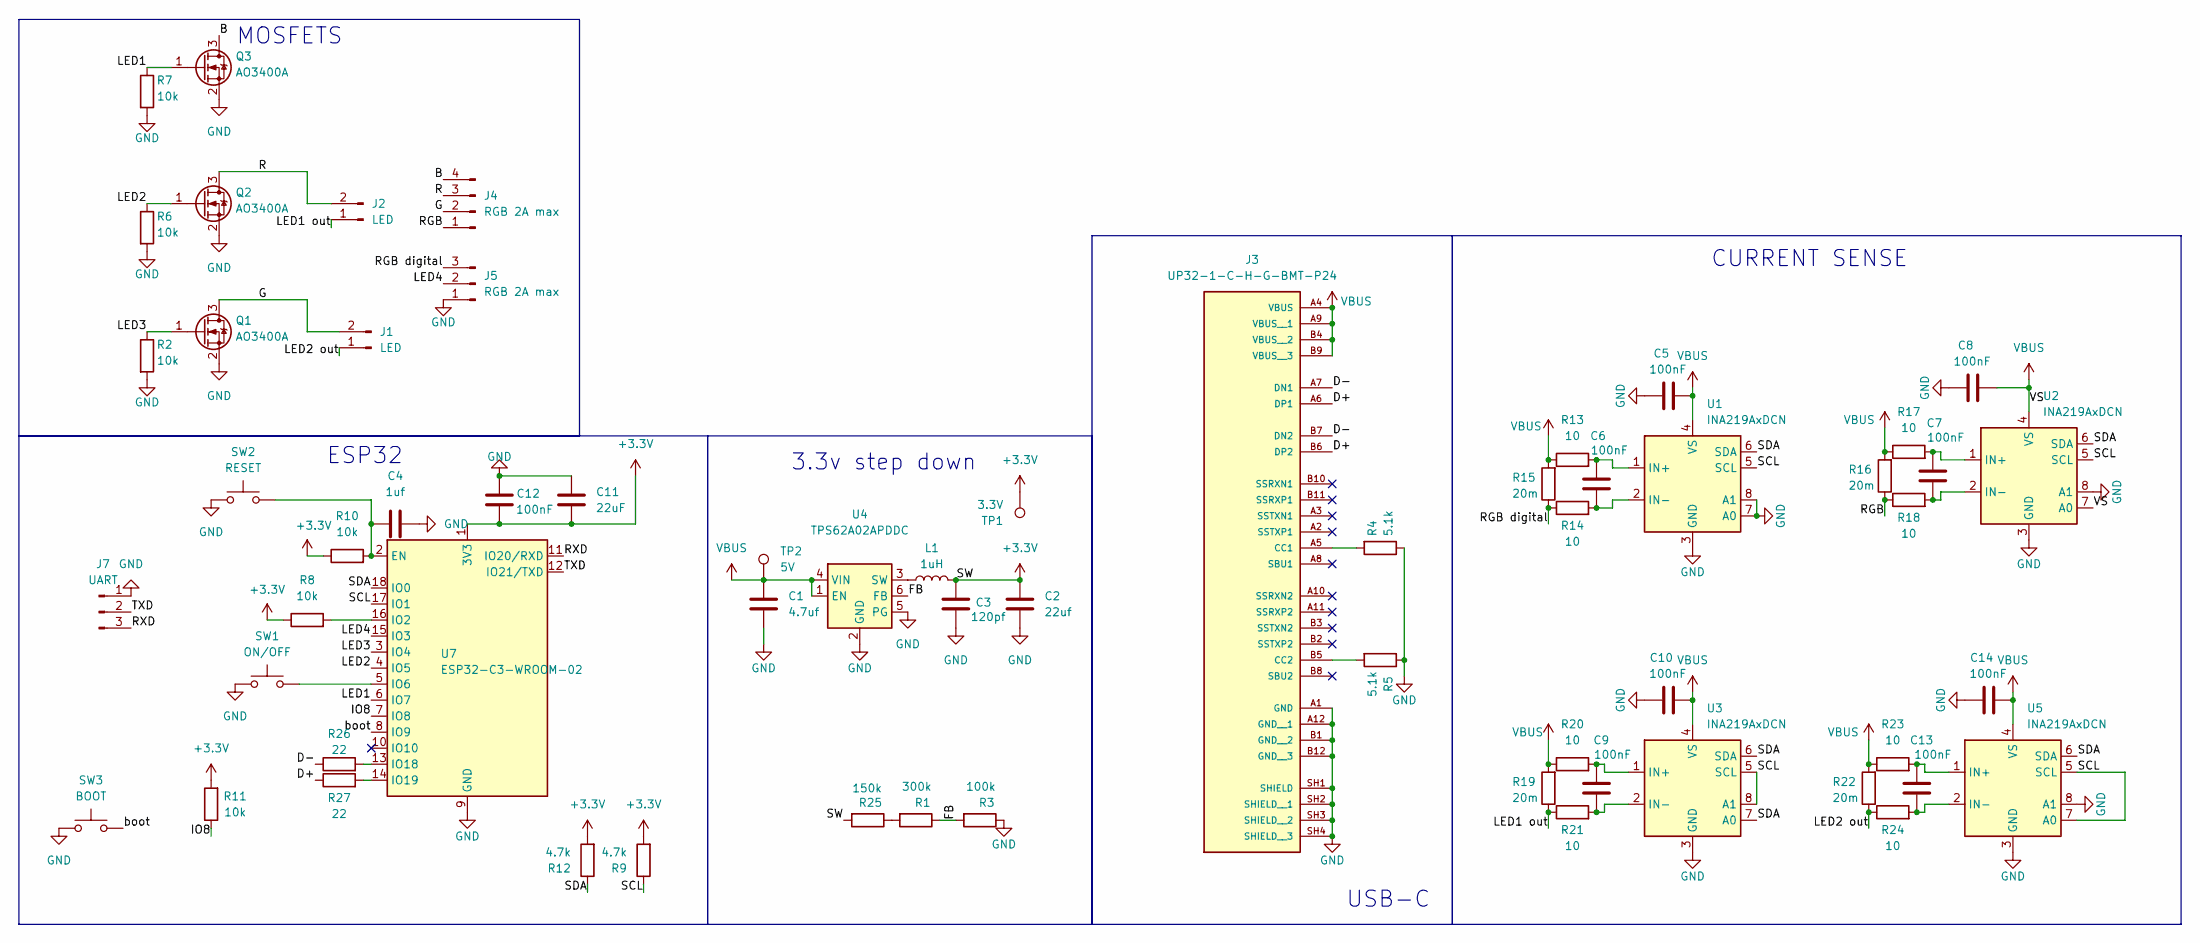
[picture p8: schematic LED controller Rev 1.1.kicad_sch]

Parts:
C1: 4.7uf; C_0603_1608Metric_Pad1.08x0.95mm_HandSolder
C2: 22uf; C_0603_1608Metric_Pad1.08x0.95mm_HandSolder
C3: 120pf; C_0402_1005Metric_Pad0.74x0.62mm_HandSolder
C4: 1uf; C_0603_1608Metric_Pad1.08x0.95mm_HandSolder
C5, C6, C7, C9, C10, C12, C13, C14: 100nF; C_0402_1005Metric_Pad0.74x0.62mm_HandSolder
C8: 100nF; C_0201_0603Metric_Pad0.64x0.40mm_HandSolder
C11: 22uF; C_0603_1608Metric_Pad1.08x0.95mm_HandSolder
J1, J2: LED; JST_XH_S2B-XH-A-1_1x02_P2.50mm_Horizontal
J3: UP32-1-C-H-G-BMT-P24; SAMESKY_UP32-1-C-H-G-BMT-P24; PARTREV 1.0
J4: RGB 2A max; JST_XH_S4B-XH-A-1_1x04_P2.50mm_Horizontal
J5: RGB 2A max; JST_XH_S3B-XH-A-1_1x03_P2.50mm_Horizontal
J7: UART; JST_ZH_B3B-ZR_1x03_P1.50mm_Vertical
L1: 1uH; L_1008_2520Metric_Pad1.43x2.20mm_HandSolder
Q1, Q2, Q3: AO3400A; SOT-23
R1: 300k; R_0402_1005Metric_Pad0.72x0.64mm_HandSolder
R2, R6, R7, R8, R10, R11: 10k; R_0603_1608Metric_Pad0.98x0.95mm_HandSolder
R3: 100k; R_0603_1608Metric_Pad0.98x0.95mm_HandSolder
R4, R5: 5.1k; R_0603_1608Metric_Pad0.98x0.95mm_HandSolder
R9, R12: 4.7k; R_0603_1608Metric_Pad0.98x0.95mm_HandSolder
R13, R14, R17, R18, R20, R21, R23, R24: 10; R_0402_1005Metric_Pad0.72x0.64mm_HandSolder
R15, R16, R19, R22: 20m; R_0805_2012Metric_Pad1.20x1.40mm_HandSolder
R25: 150k; R_0402_1005Metric_Pad0.72x0.64mm_HandSolder
R26, R27: 22; R_0402_1005Metric_Pad0.72x0.64mm_HandSolder
SW1: ON/OFF; SW_SPST_B3U-1000P
SW2: RESET; SW_SPST_B3U-1000P
SW3: BOOT; SW_SPST_B3U-1000P
TP1: 3.3V; TestPoint_Pad_D1.0mm
TP2: 5V; TestPoint_Pad_D1.0mm
U1, U2, U3, U5: INA219AxDCN; SOT-23-8
U4: TPS62A02APDDC; SOT-23-6
U7: ESP32-C3-WROOM-02; ESP32-C3-WROOM-02U

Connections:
+3.3V: C2.1, C3.1, C11.2, C12.2, L1.2, R8.1, R9.2, R10.1, R11.2, R12.2, R25.2, TP1.1 (1_1), U7.1 (3V3)
/B: J4.4, Q3.3 (D)
/D+: J3.A6 (DP1), J3.B6 (DP2), R27.1
/D-: J3.A7 (DN1), J3.B7 (DN2), R26.1
/FB: R1.1, R3.2, U4.6 (FB)
/G: J1.2, J4.2, Q1.3 (D)
/IO8: R11.1, U7.7 (IO8)
/LED1: Q3.1 (G), R7.1, U7.6 (IO7)
/LED1 out: J2.1, R19.1, R21.1
/LED2: Q2.1 (G), R6.1, U7.4 (IO5)
/LED2 out: J1.1, R22.1, R24.1
/LED3: Q1.1 (G), R2.1, U7.3 (IO4)
/LED4: J5.2, U7.15 (IO3)
/R: J2.2, J4.3, Q2.3 (D)
/RGB: J4.1, R16.1, R18.1
/RGB digital: J5.3, R14.1, R15.1
/RXD: J7.3, U7.11 (IO20/RXD)
/SCL: R9.1, U1.5 (SCL), U2.5 (SCL), U3.5 (SCL), U3.8 (A1), U5.5 (SCL), U5.7 (A0), U7.17 (IO1)
/SDA: R12.1, U1.6 (SDA), U2.6 (SDA), U3.6 (SDA), U3.7 (A0), U5.6 (SDA), U7.18 (IO0)
/TXD: J7.2, U7.12 (IO21/TXD)
/boot: SW3.2, U7.8 (IO9)
GND: C1.2, C2.2, C3.2, C4.1, C5.1, C8.1, C10.1, C11.1, C12.1, C14.1, J3.A1 (GND), J3.A12 (GND__1), J3.B1 (GND__2), J3.B12 (GND__3), J3.SH1 (SHIELD), J3.SH2 (SHIELD__1), J3.SH3 (SHIELD__2), J3.SH4 (SHIELD__3), J5.1, J7.1, Q1.2 (S), Q2.2 (S), Q3.2 (S), R2.2, R3.1, R4.1, R5.1, R6.2, R7.2, SW1.1, SW2.1, SW3.1, U1.3 (GND), U1.7 (A0), U1.8 (A1), U2.3 (GND), U2.8 (A1), U3.3 (GND), U4.2 (GND), U4.5 (PG), U5.3 (GND), U5.8 (A1), U7.9 (GND), U7.19 (GND)
unnamed: J3.A5 (CC1), R4.2
unnamed: J3.B5 (CC2), R5.2
unnamed: R1.2, R25.1
unnamed: C6.1, R13.2, U1.1 (IN+)
unnamed: C6.2, R14.2, U1.2 (IN-)
unnamed: C7.1, R17.2, U2.1 (IN+)
unnamed: C7.2, R18.2, U2.2 (IN-)
unnamed: C9.1, R20.2, U3.1 (IN+)
unnamed: C9.2, R21.2, U3.2 (IN-)
unnamed: L1.1, U4.3 (SW)
unnamed: C13.1, R23.2, U5.1 (IN+)
unnamed: C13.2, R24.2, U5.2 (IN-)
unnamed: C4.2, R10.2, SW2.2, U7.2 (EN)
unnamed: R8.2, U7.16 (IO2)
unnamed: SW1.2, U7.5 (IO6)
unnamed: R26.2, U7.13 (IO18)
unnamed: R27.2, U7.14 (IO19)
VBUS: C1.1, C5.2, C8.2, C10.2, C14.2, J3.A4 (VBUS), J3.A9 (VBUS__1), J3.B4 (VBUS__2), J3.B9 (VBUS__3), R13.1, R15.2, R16.2, R17.1, R19.2, R20.1, R22.2, R23.1, TP2.1 (1_1), U1.4 (VS), U2.4 (VS), U2.7 (A0), U3.4 (VS), U4.1 (EN), U4.4 (VIN), U5.4 (VS)

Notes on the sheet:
ESP32
USB-C
CURRENT SENSE
3.3v step down
MOSFETS

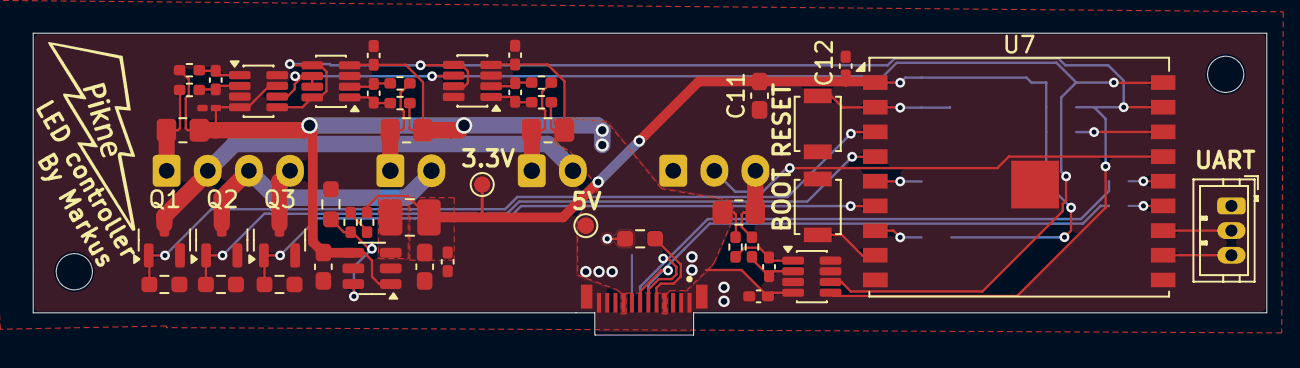
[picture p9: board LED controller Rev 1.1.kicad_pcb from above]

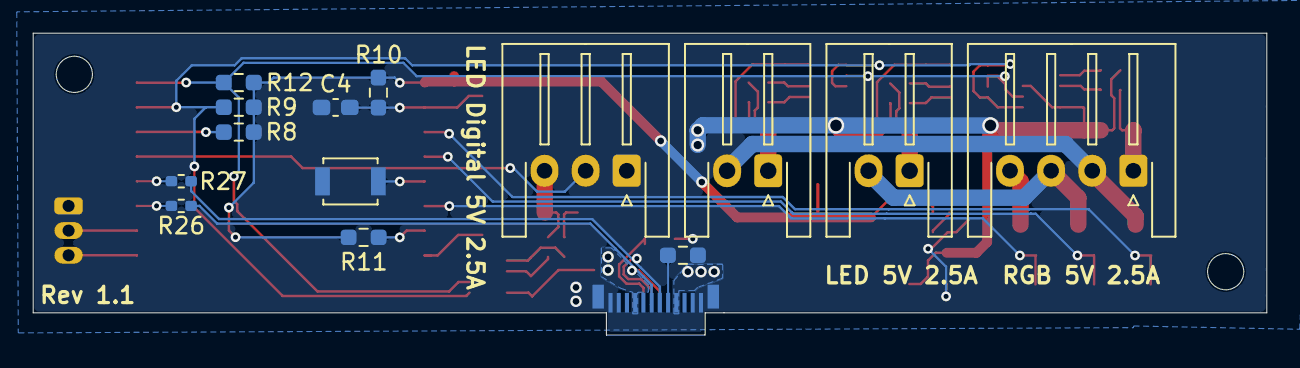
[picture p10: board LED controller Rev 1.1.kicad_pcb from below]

Board: 2 copper layers, 75.0 x 18.4 mm, 62 parts (14 on the bottom side), 40 nets.

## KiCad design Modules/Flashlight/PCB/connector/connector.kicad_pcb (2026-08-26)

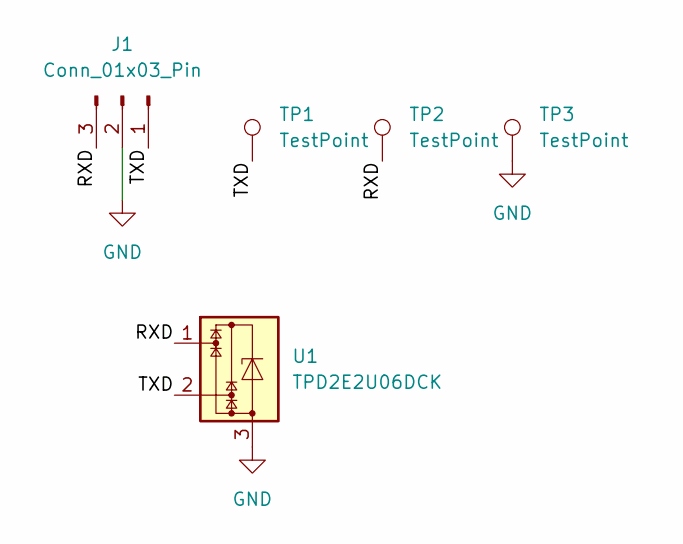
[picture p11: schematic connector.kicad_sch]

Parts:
J1: Conn_01x03_Pin; Pogo 3 Pin
TP1, TP2, TP3: TestPoint; TestPoint_Pad_D1.0mm
U1: TPD2E2U06DCK; SOT-323_SC-70

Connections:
/RXD: J1.3, TP2.1 (1_1), U1.1
/TXD: J1.1, TP1.1 (1_1), U1.2
GND: J1.2, TP3.1 (1_1), U1.3

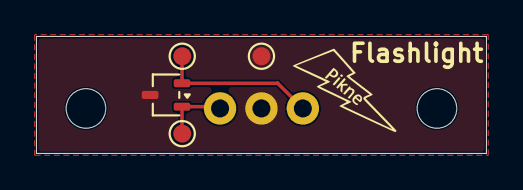
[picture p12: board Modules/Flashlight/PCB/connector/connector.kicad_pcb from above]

Board: 2 copper layers, 25.0 x 6.5 mm, 5 parts (1 on the bottom side), 3 nets.

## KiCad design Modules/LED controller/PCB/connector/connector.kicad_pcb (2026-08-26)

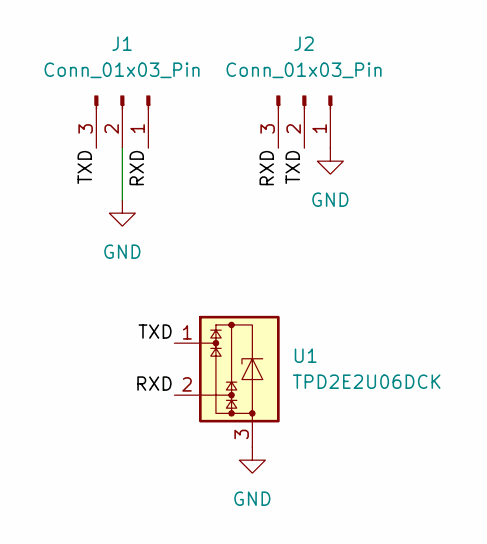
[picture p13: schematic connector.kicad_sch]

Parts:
J1: Conn_01x03_Pin; Pogo 3 Pin
J2: Conn_01x03_Pin; JST_ZH_S3B-ZR-SM4A-TF_1x03-1MP_P1.50mm_Horizontal
U1: TPD2E2U06DCK; SOT-323_SC-70

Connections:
/RXD: J1.1, J2.3, U1.2
/TXD: J1.3, J2.2, U1.1
GND: J1.2, J2.1, U1.3


Board: 2 copper layers, 37.5 x 10.0 mm, 3 parts (1 on the bottom side), 3 nets.

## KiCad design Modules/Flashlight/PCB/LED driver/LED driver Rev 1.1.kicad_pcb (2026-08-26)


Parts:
C1, C2: 10uf; C_1206_3216Metric
C3, C19, C21: 1uf; C_0402_1005Metric
C4: 470pf; C_0402_1005Metric
C7, C25, C26, C30, C31, C37, C39: 0.1uf; C_0402_1005Metric
C17, C18, C24: 1uf; C_0603_1608Metric
C27, C29, C38: 10uf; C_0603_1608Metric
C28: 22uf; C_0805_2012Metric
C32: 47pf; R_0402_1005Metric
D1: 810ma; D_SMF
D2: D_Schottky; D_SOD-323_HandSoldering
D7: LED; LED_0603_1608Metric
IC1: LM3409MY_NOPB; SOP50P490X109-11N; Mouser Part Number 926-LM3409MY/NOPB
J1: USB4180-03-0120-C; USB4180030120C; Mouser Part Number 640-USB4180-03-0120C
J3: NTC; JST_ZH_B2B-ZR_1x02_P1.50mm_Vertical
J5: UART; JST_ZH_B3B-ZR_1x03_P1.50mm_Vertical
J6: Conn_01x04_Socket; JST_ZH_B4B-ZR_1x04_P1.50mm_Vertical
J7: LED; JST_XH_S2B-XH-A-1_1x02_P2.50mm_Horizontal
L1: 15uh; L_Bourns_SRP1038C_10.0x10.0mm
L2: 3.3uh; INDC3225X120N
Q1: SISA35DN-T1-GE3; SISA35DNT1GE3; Mouser Part Number 78-SISA35DN-T1-GE3
Q10: DMP3014SFDE-13; DMP1022UFDEQ7; Manufacturer_Part_Number DMP3014SFDE-13
R1, R3, R34: 10k; R_0603_1608Metric
R2, R38: 100k; R_0603_1608Metric
R4: 20m; R_1206_3216Metric
R5: 24.9k; R_0603_1608Metric
R6: 71.5k; R_0603_1608Metric
R12: 1k; R_0402_1005Metric
R36: 470; R_0603_1608Metric
R37: 1k; R_0603_1608Metric
R39: 22k; R_0603_1608Metric
R40, R41: 100; R_0402_1005Metric
R42, R43, R44: 4.7k; R_0603_1608Metric
R45: 30k; R_0402_1005Metric
R46: 100k; R_0402_1005Metric
R47: 50k; R_0402_1005Metric
R48: 135k; R_0402_1005Metric
R50: 10k; R_0402_1005Metric
SW1: SW_Push; SW_Tactile_SPST_Angled_PTS645Vx39-2LFS
SW3: SW_Push; SW_SPST_B3U-1000P
TP1, TP2, TP3: TestPoint; TestPoint_Pad_D1.0mm
U1: TVS2200DRV; WSON-6-1EP_2x2mm_P0.65mm_EP1x1.6mm
U2: STUSB4500QTR; QFN-24-1EP_4x4mm_P0.5mm_EP2.7x2.7mm
U4: STM32L011F3Px; TSSOP-20_4.4x6.5mm_P0.65mm
U5: TPS562246DRLR; SOTFL50P160X60-6N; Mouser Part Number 595-TPS562246DRLR

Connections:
+3.3V: C24.1, C25.1, C28.1, C32.1, C38.2, C39.2, L2.1, R1.2, R42.1, R43.1, R44.1, R48.2, TP1.1 (1_1), U4.5 (VDDA), U4.16 (VDD)
/3.3V EN: R46.1, R47.2, U5.5 (EN)
/ALERT: R44.2, U2.19 (ALERT), U4.13 (PA7)
/BST: C31.2, U5.4 (BST)
/CC1: J1.A5 (CC1), U2.2 (CC1)
/CC2: J1.B5 (CC2), U2.4 (CC2)
/D: D1.1 (K), L1.1, Q1.5 (D_1), Q1.6 (D_2), Q1.7 (D_3), Q1.8 (D_4), Q1.9 (D_5), Q1.10 (D_6), Q1.11 (D_7), R5.1
/G: IC1.6 (PGATE), Q1.4 (G)
/LED: R40.2, U4.11 (PA5)
/LED driver EN: IC1.3 (EN), U4.9 (PA3)
/NRST: C37.2, J6.1, SW3.2, U4.4 (NRST)
/NTC: C7.1, R12.1, U4.14 (PB1)
/Nupp: SW1.1, U4.8 (PA2)
/RX: J5.2, U4.6 (PA0)
/S: IC1.7 (CSN), Q1.1 (S_1), Q1.2 (S_2), Q1.3 (S_3), R4.2
/SCL: R42.2, U2.7 (SCL), U4.17 (PA9)
/SDA: R43.2, U2.8 (SDA), U4.18 (PA10)
/SW: C31.1, L2.2, U5.2 (SW)
/SWCLK: J6.3, U4.20 (PA14)
/SWDIO: J6.2, U4.19 (PA13)
/TX: J5.3, U4.7 (PA1)
/VBUS_VS_DISCH: R37.2, U2.18 (VBUS_VS_DISCH)
GND: C1.2, C2.2, C4.2, C7.2, C17.1, C18.1, C19.1, C21.1, C24.2, C25.2, C27.2, C28.2, C29.2, C30.2, C37.1, C38.1, C39.1, D1.2 (A), D7.1 (K), IC1.5 (GND), IC1.11 (DAP), J1.1 (MH1), J1.2 (MH2), J1.3 (MH3), J1.4 (MH4), J1.A12 (GND_1), J1.B12 (GND_2), J3.1, J5.1, J6.4, J7.1, R3.1, R6.1, R34.2, R45.2, R47.1, R50.2, SW1.2, SW3.1, TP2.1 (1_1), U1.1 (GND), U1.2 (GND), U1.3 (GND), U1.7 (GND), U2.1 (CC1DB), U2.5 (CC2DB), U2.10 (GND), U2.12 (ADDR0), U2.13 (ADDR1), U2.22 (VSYS), U2.25 (GND), U4.15 (VSS), U5.3 (GND)
unnamed: C26.2, R41.2
unnamed: C18.2, D2.2 (A), J1.A9 (VBUS_1), J1.B9 (VBUS_2), Q10.4 (S_1), Q10.8 (S_2), R36.1, R38.1, U1.4 (IN), U1.5 (IN), U1.6 (IN), U2.24 (VDD)
unnamed: C17.2, D2.1 (K), R36.2, R37.1
unnamed: D7.2 (A), R40.1
unnamed: C4.1, IC1.4 (COFF), R5.2
unnamed: IC1.2 (IADJ), R6.2
unnamed: IC1.1 (UVLO), R2.1, R3.2
unnamed: C3.2, IC1.9 (VCC)
unnamed: J3.2, R1.1, R12.2
unnamed: J7.2, L1.2
unnamed: Q10.3 (G), R38.2, R39.1, R41.1
unnamed: R34.1, U2.6 (RESET)
unnamed: R39.2, U2.16 (VBUS_EN_SNK)
unnamed: C19.2, U2.21 (VREG_1V2)
unnamed: C21.2, U2.23 (VREG_2V7)
unnamed: R50.1, U4.1 (PB9)
unnamed: C32.2, R45.1, R48.1, U5.6 (FB)
VBUS: C1.1, C2.1, C3.1, C26.1, C27.1, C29.1, C30.1, IC1.8 (CSP), IC1.10 (VIN), Q10.1 (D_1), Q10.2 (D_2), Q10.5 (D_3), Q10.6 (D_4), Q10.7 (D_5), R2.2, R4.1, R46.2, TP3.1 (1_1), U5.1 (VIN)

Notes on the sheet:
3.3V
LED driver
USB-C
STM32



Board: 2 copper layers, 73.0 x 20.8 mm, 65 parts (34 on the bottom side), 41 nets.

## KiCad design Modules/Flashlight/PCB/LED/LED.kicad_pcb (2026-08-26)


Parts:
D1, D2, D3, D4, D5, D6, D7, D8, D9, D10, D11, D12, D13, D14, D15, D16, D17, D18, D19, D20, D21, D22, D23, D24, D25, D26, D27, D29, D30, D31: LED; Q9LR37
TH1: Thermistor_NTC; R_0402_1005Metric
TP1, TP2: TestPoint; TestPoint_Pad_D3.0mm
TP3: TestPoint; TestPoint_Pad_D1.5mm

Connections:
GND: D1.1 (K), D4.1 (K), D7.1 (K), D8.1 (K), D13.1 (K), D14.1 (K), D15.1 (K), D16.1 (K), D21.1 (K), D22.1 (K), D23.1 (K), D24.1 (K), D29.1 (K), D30.1 (K), D31.1 (K), TH1.2, TP2.1 (1_1)
unnamed: D1.2 (A), D2.1 (K)
unnamed: D3.1 (K), D4.2 (A)
unnamed: D5.1 (K), D7.2 (A)
unnamed: D6.1 (K), D8.2 (A)
unnamed: D10.1 (K), D14.2 (A)
unnamed: D11.1 (K), D15.2 (A)
unnamed: D12.1 (K), D16.2 (A)
unnamed: D9.1 (K), D13.2 (A)
unnamed: D17.1 (K), D21.2 (A)
unnamed: D18.1 (K), D22.2 (A)
unnamed: D19.1 (K), D23.2 (A)
unnamed: D20.1 (K), D24.2 (A)
unnamed: D25.1 (K), D29.2 (A)
unnamed: D26.1 (K), D30.2 (A)
unnamed: D27.1 (K), D31.2 (A)
unnamed: TH1.1, TP3.1 (1_1)
VDD: D2.2 (A), D3.2 (A), D5.2 (A), D6.2 (A), D9.2 (A), D10.2 (A), D11.2 (A), D12.2 (A), D17.2 (A), D18.2 (A), D19.2 (A), D20.2 (A), D25.2 (A), D26.2 (A), D27.2 (A), TP1.1 (1_1)


Board: 2 copper layers, 74.0 x 21.5 mm, 34 parts (0 on the bottom side), 18 nets.

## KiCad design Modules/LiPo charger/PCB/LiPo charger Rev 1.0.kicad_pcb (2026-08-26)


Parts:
C1, C2, C3, C8: 10uf; C_1206_3216Metric
C4, C5, C6, C7, C12, C13, C20, C23, C26, C30, C31, C33: 0.1uf; C_0402_1005Metric
C9: 200pf; C_0402_1005Metric
C10: 4.7uf; C_0603_1608Metric
C11, C14, C15, C16: 22uf; C_1206_3216Metric
C17, C18, C24: 1uf; C_0603_1608Metric
C19, C21: 1uf; C_0402_1005Metric
C22, C27, C29: 10uf; C_0603_1608Metric
C25: 0.1uf; R_0402_1005Metric
C28: 22uf; C_0805_2012Metric
C32: 47pf; C_0201_0603Metric
D1: D_Zener; D_SOD-323_HandSoldering
D2: D_Schottky; D_SOD-323_HandSoldering
IC1, IC3, IC4: ISOM8111DFGR; SOP254P700X240-4N; Manufacturer_Part_Number ISOM8111DFGR
IC2: TPS55288RPMR; Mouser Part Number 595-TPS55288RPMR
J1: Battery; JST_VH_B2P-VH-B_1x02_P3.96mm_Vertical
J2: Conn_01x05_Socket; JST_XH_S5B-XH-A_1x05_P2.50mm_Horizontal
J3: UP32-1-C-H-G-BMT-P24; SAMESKY_UP32-1-C-H-G-BMT-P24; PARTREV 1.0
J4: FFC2B35-06-G; FFC2B3506G; Mouser Part Number 640-FFC2B35-06-G
J5: UART; JST_ZH_B3B-ZR_1x03_P1.50mm_Vertical
J6: Conn_01x04_Socket; JST_ZH_B4B-ZR_1x04_P1.50mm_Vertical
L1: 4.7uh; L_Bourns_SRP1038C_10.0x10.0mm
L2: 3.3uh; INDC3225X120N
NT1: NetTie_2; NetTie-2_SMD_Pad0.5mm
Q1, Q2, Q5, Q6, Q9: AO3400A; SOT-23
Q3, Q4: NTTFS5C454NLTAG; WDFN8_3.3X3.3_0.65P_CASE_511AB_ISSUE_D_1; Mouser Part Number 863-NTTFS5C454NLTAG
Q7, Q8, Q10: DMP3014SFDE-13; DMP1022UFDEQ7; Manufacturer_Part_Number DMP3014SFDE-13
R1, R6, R24, R28, R40: 10k; R_0402_1005Metric
R2, R13, R25, R30: 50; R_0603_1608Metric
R3, R14, R26: 430; R_0603_1608Metric
R4: 6.19k; R_0603_1608Metric
R5, R19, R27: 220; R_0603_1608Metric
R7: 49.9k; R_0402_1005Metric
R8: 20k; R_0603_1608Metric
R9, R10, R11, R12: 1k; R_0402_1005Metric
R15, R16, R17, R18, R38: 100k; R_0603_1608Metric
R20, R21, R22, R23: 22k; R_0402_1005Metric
R29: 150k; R_0402_1005Metric
R31, R34, R35: 10k; R_0603_1608Metric
R32: 10m; R_1206_3216Metric
R33: 100; R_0603_1608Metric
R36: 470; R_0402_1005Metric
R37: 1k; R_0603_1608Metric
R39: 22k; R_0603_1608Metric
R41: 100; R_0402_1005Metric
R42, R43, R44: 4.7k; R_0603_1608Metric
R45: 30k; R_0402_1005Metric
R46: 100k; R_0402_1005Metric
R47: 50k; R_0402_1005Metric
R48: 135k; R_0402_1005Metric
SW1: SW_Push; SW_SPST_B3U-1000P
TP1, TP2, TP3: TestPoint; TestPoint_Pad_D1.0mm
U1: TVS2200DRV; WSON-6-1EP_2x2mm_P0.65mm_EP1x1.6mm
U2: STUSB4500QTR; QFN-24-1EP_4x4mm_P0.5mm_EP2.7x2.7mm
U3: ER_OLEDM0.91_1x-I2C
U4: STM32L011G3Ux; QFN-28_4x4mm_P0.5mm
U5: TPS562246DRLR; SOTFL50P160X60-6N; Mouser Part Number 595-TPS562246DRLR

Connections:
+3.3V: C22.2, C23.2, C24.1, C25.1, C28.1, C32.1, L2.1, R42.1, R43.1, R44.1, R48.2, TP1.1 (1_1), U3.2 (VCC), U4.5 (VDDA), U4.17 (VDD)
+BATT: IC4.4 (COL), J1.2, J2.5, Q8.1 (D_1), Q8.2 (D_2), Q8.5 (D_3), Q8.6 (D_4), Q8.7 (D_5), R15.2, R30.1
/3.3V EN: R46.1, R47.2, U5.5 (EN)
/ALERT: R44.2, U2.19 (ALERT), U4.2 (PC14)
/BOOT1: C12.2, IC2.22 (BOOT1)
/BOOT2: C13.2, IC2.20 (BOOT2)
/BST: C31.2, U5.4 (BST)
/Bat fets: Q9.1 (G), R35.1, U4.18 (PA8)
/Button down: J4.1, U4.25 (PB4)
/Button left: J4.2, U4.26 (PB5)
/Button right: J4.4, U4.10 (PA4)
/Button up: J4.5, U4.3 (PC15)
/CC1: J3.A5 (CC1), U2.2 (CC1)
/CC2: J3.B5 (CC2), U2.4 (CC2)
/COMP: IC2.18 (COMP), R29.1
/Cell1: J2.2, Q2.2 (S), R2.1, R6.2, R16.2
/Cell1 sense: C5.1, R10.1, U4.6 (PA0)
/Cell2: IC1.4 (COL), J2.3, Q5.2 (S), R13.1, R17.2, R24.2
/Cell2 sense: C6.1, R11.1, U4.7 (PA1)
/Cell3: IC3.4 (COL), J2.4, Q6.2 (S), R18.2, R25.1, R28.2
/Cell3 sense: C7.1, R12.1, U4.8 (PA2)
/Cell 1 balance: Q1.1 (G), R1.1, U4.12 (PA6)
/Cell 2 balance: R3.1, U4.13 (PA7)
/Cell 3 balance: R14.1, U4.14 (PB0)
/Cell 4 balance: R26.1, U4.15 (PB1)
/DR1L: IC2.1 (DR1L_1), IC2.27 (DR1L_2), Q4.4 (G)
/FSW: IC2.8 (FSW), R7.1
/ILIM: IC2.17 (ILIM), R8.1
/ISN: IC2.13 (ISN_1), IC2.29 (ISN_2), Q7.1 (D_1), Q7.2 (D_2), Q7.5 (D_3), Q7.6 (D_4), Q7.7 (D_5), R32.2
/ISP: C11.1, C14.1, C15.1, C16.1, IC2.11 (VOUT_1), IC2.12 (ISP), IC2.26 (VOUT_2), R32.1
/MODE: IC2.15 (MODE), R4.1
/NRST: C20.2, J6.1, SW1.2, U4.4 (NRST)
/OK: J4.3, U4.11 (PA5)
/Pack: C4.1, R9.1, U4.9 (PA3)
/RX: J5.2, U4.28 (PB7)
/Regulator EN: IC2.4 (EN/UVLO), U4.24 (PB3)
/Regulator INT: IC2.14 (FB/~INT), U4.23 (PA15)
/SCL: IC2.5 (SCL), R42.2, U2.7 (SCL), U3.3 (SCL), U4.19 (PA9)
/SDA: IC2.6 (SDA), R43.2, U2.8 (SDA), U3.4 (SDA), U4.20 (PA10)
/SW: C31.1, L2.2, U5.2 (SW)
/SW1: C12.1, IC2.23 (SW1), L1.1, Q3.1 (S_1), Q3.2 (S_2), Q3.3 (S_3), Q4.5 (D_1), Q4.6 (D_2), Q4.7 (D_3), Q4.8 (D_4), Q4.9, Q4.10, Q4.11
/SW2: C13.1, IC2.21 (SW2_1), IC2.25 (SW2_2), L1.2
/SWCLK: J6.3, U4.22 (PA14)
/SWDIO: J6.2, U4.21 (PA13)
/TX: J5.3, U4.27 (PB6)
/VBUS_VS_DISCH: R37.2, U2.18 (VBUS_VS_DISCH)
/VCC: C10.1, IC2.19 (VCC_1), IC2.30 (VCC_2)
GND: C1.2, C2.2, C3.2, C4.2, C5.2, C6.2, C7.2, C8.2, C11.2, C14.2, C15.2, C16.2, C17.1, C18.1, C19.1, C20.1, C21.1, C22.1, C23.1, C24.2, C25.2, C27.2, C28.2, C29.2, C30.2, C33.2, D1.2 (A), IC1.2 (CAT), IC2.9 (PGND_1), IC2.24 (PGND_2), IC3.2 (CAT), IC4.2 (CAT), J1.1, J2.1, J3.A1 (GND), J3.A12 (GND__1), J3.B1 (GND__2), J3.B12 (GND__3), J3.SH1 (SHIELD), J3.SH2 (SHIELD__1), J3.SH3 (SHIELD__2), J3.SH4 (SHIELD__3), J4.6, J4.MP1, J4.MP2, J5.1, J6.4, NT1.1, Q1.2 (S), Q4.1 (S_1), Q4.2 (S_2), Q4.3 (S_3), Q9.2 (S), R1.2, R20.1, R21.1, R22.1, R23.1, R34.2, R35.2, R40.2, R45.2, R47.1, SW1.1, TP2.1 (1_1), U1.1 (GND), U1.2 (GND), U1.3 (GND), U1.7 (GND), U2.1 (CC1DB), U2.5 (CC2DB), U2.10 (GND), U2.12 (ADDR0), U2.13 (ADDR1), U2.22 (VSYS), U2.25 (GND), U3.1 (GND), U4.16 (VSS), U5.3 (GND)
GNDA: C9.2, C10.2, IC2.7 (DITH/SYNC_1), IC2.10 (AGND), IC2.28 (DITH/SYNC_2), NT1.2, R4.2, R7.2, R8.2
unnamed: C9.1, R29.2
unnamed: C26.2, R41.2
unnamed: D1.1 (K), Q9.3 (D), R33.2
unnamed: C18.2, D2.2 (A), J3.A4 (VBUS), J3.A9 (VBUS__1), J3.B4 (VBUS__2), J3.B9 (VBUS__3), Q10.4 (S_1), Q10.8 (S_2), R36.1, R38.1, U1.4 (IN), U1.5 (IN), U1.6 (IN), U2.24 (VDD)
unnamed: C17.2, D2.1 (K), R36.2, R37.1
unnamed: IC1.1 (AN), R3.2
unnamed: IC1.3 (EM), R5.2
unnamed: IC2.2 (DR1H), Q3.4 (G)
unnamed: IC3.1 (AN), R14.2
unnamed: IC3.3 (EM), R19.2
unnamed: IC4.1 (AN), R26.2
unnamed: IC4.3 (EM), R27.2
unnamed: Q1.3 (D), R2.2
unnamed: Q2.3 (D), R13.2
unnamed: Q2.1 (G), R5.1, R6.1
unnamed: Q5.3 (D), R25.2
unnamed: Q5.1 (G), R19.1, R24.1
unnamed: Q6.3 (D), R30.2
unnamed: Q6.1 (G), R27.1, R28.1
unnamed: Q7.3 (G), Q8.3 (G), R31.1, R33.1
unnamed: Q7.4 (S_1), Q7.8 (S_2), Q8.4 (S_1), Q8.8 (S_2), R31.2
unnamed: Q10.3 (G), R38.2, R39.1, R41.1
unnamed: R10.2, R16.1, R21.2
unnamed: R11.2, R17.1, R22.2
unnamed: R12.2, R18.1, R23.2
unnamed: R9.2, R15.1, R20.2
unnamed: R34.1, U2.6 (RESET)
unnamed: R39.2, U2.16 (VBUS_EN_SNK)
unnamed: C19.2, U2.21 (VREG_1V2)
unnamed: C21.2, U2.23 (VREG_2V7)
unnamed: R40.1, U4.1 (PB9)
unnamed: C32.2, R45.1, R48.1, U5.6 (FB)
VBUS: C1.1, C2.1, C3.1, C8.1, C26.1, C27.1, C29.1, C30.1, C33.1, IC2.3 (VIN), Q3.5 (D_1), Q3.6 (D_2), Q3.7 (D_3), Q3.8 (D_4), Q3.9, Q3.10, Q3.11, Q10.1 (D_1), Q10.2 (D_2), Q10.5 (D_3), Q10.6 (D_4), Q10.7 (D_5), R46.2, TP3.1 (1_1), U5.1 (VIN)

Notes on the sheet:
Buck boost regulator
3.3V
Battery sense and balance
USB-C
STM32



Board: 2 copper layers, 72.0 x 26.7 mm, 115 parts (17 on the bottom side), 82 nets.

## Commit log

2026-08-02 Update README.md
    Added capacity to features, LiPo charger to modules and changed name
2026-08-04 Added LiPo charger module PCB files
    [LiPo charger Rev 1.0.kicad_pcb, LiPo charger Rev 1.0.kicad_sch]
2026-08-17 Added flashlight module
    [LED Driver Rev 1.1.kicad_pcb, LED Driver Rev 1.1.kicad_sch, LED.kicad_pcb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]
2026-08-26 Added everything
    [BMS Rev 1.1.kicad_pcb, LED controller Rev 1.1.kicad_pcb, LED controller Rev 1.1.kicad_sch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]
2026-08-29 Removing old PCB files
    [Pikne Rev 1.0.kicad_pcb, Pikne Rev 1.0.kicad_sch]
2026-08-29 Added new PCB files
    [Pikne Rev 1.1.kicad_pcb, Pikne Rev 1.1.kicad_sch]
2026-09-13 Added BOMs and updated some PCB files
    [BMS Rev 1.1.csv, BMS Rev 1.1.kicad_pcb, BMS Rev 1.1.kicad_sch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]
2026-09-15 Update BMS Rev 1.1.csv
    [BMS Rev 1.1.csv]
2026-09-15 Rename BMS Rev 1.1.csv to BOM.csv
    [BOM.csv]
2026-10-18 Added pictures for wiring
2026-10-18 Updated BOM
2026-10-29 Made a correction in the BOM
2026-11-04 Delete CAD/Assembly.zip
    Changing from .zip to .step
2026-11-04 Added .step assembly
2026-11-04 Changed LED controller and flashlight assemblies from .zip to .step
